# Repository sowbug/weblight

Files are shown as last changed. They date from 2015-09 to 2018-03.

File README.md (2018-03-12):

# WebLight

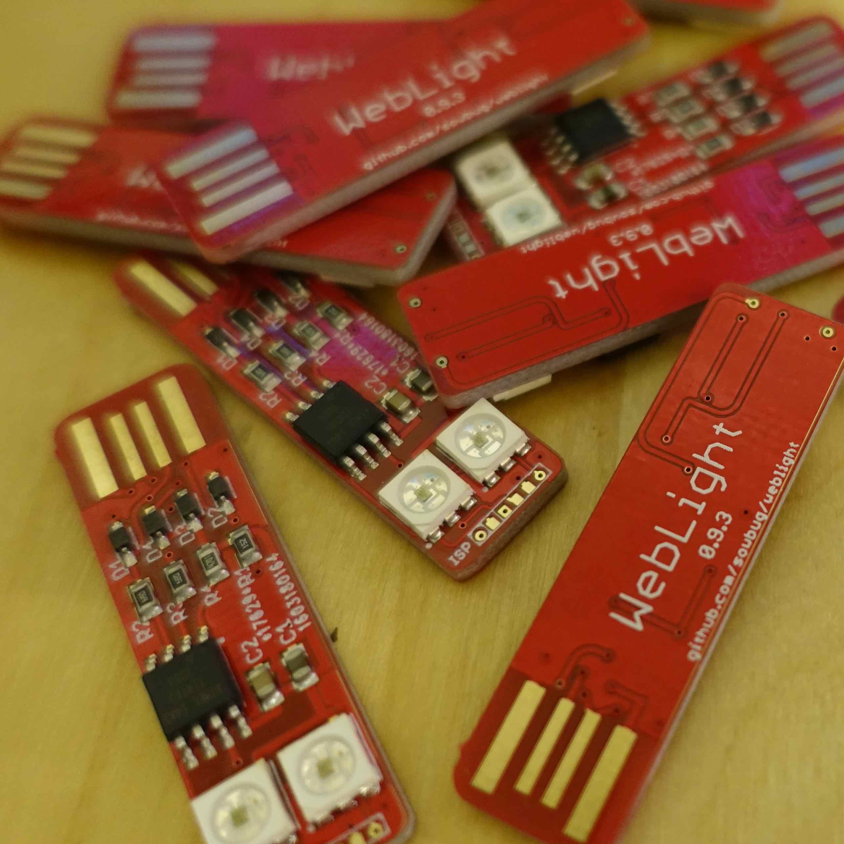
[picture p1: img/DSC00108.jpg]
WebLight


A USB-controlled LED designed for the
[WebUSB API](https://wicg.github.io/webusb/).

Try the web app
===
Have a WebLight device already?  
Launch the web app here:  
https://sowbug.github.io/weblight/

What does the javascript look like to write color values?  
Check out [software/src/weblight-card.html](https://github.com/sowbug/weblight/blob/master/software/src/weblight-card.html)

Developing WebLight Devices
===

Toolchain/environment setup
---

* Install avr-gcc. On Windows, download avr-gcc from
http://andybrown.me.uk/2015/03/08/avr-gcc-492/. Make sure you've
installed a base MinGW and MSYS system or equivalent, and have them in
your system path. On Linux, try something like `sudo apt-get install
gcc-avr binutils-avr gdb-avr avr-libc avrdude`. On OS X,
[CrossPack](https://www.obdev.at/products/crosspack/index.html) works.
* Install libusb. `sudo apt-get install libusb-dev` works on
  Linux, and `brew install libusb libusb-compat` works on OS X.
* Install pyusb. `sudo apt-get install python-usb` on Linux, or `sudo pip
  install pyusb` on other platforms.
* Build and install the
  [micronucleus command-line tool](https://github.com/micronucleus/micronucleus/tree/master/commandline)
  to be able to upload to the ATTiny85. Have it somewhere in your PATH. Don't forget [the udev rule](https://raw.githubusercontent.com/micronucleus/micronucleus/master/commandline/49-micronucleus.rules) if needed.
* Copy the files in `udev` to `/etc/udev/rules.d/` and then `sudo
  udevadm control --reload-rules`.

Programming a newly built board
---

* Connect a 6-pin AVR programmer. Note that if you've built the
  production version of the board, you'll need either an SOIC-8 clip
  manually wired for the ATtiny85, or else a
  [ProtoProg](http://protofusion.org/wordpress/2013/05/open-hardware-pogo-pin-programmer/)
  programming
  adapter. [This is the project I ordered](https://oshpark.com/shared_projects/fqvxyzoH)
  from OSH Park, and you'll want [0.68mm diameter, 16mm length pogo
  pins](http://www.ebay.com/sch/i.html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), probably from eBay.
* `cd firmware`
* Configure the makefile to talk to your type of programmer (default
usbtiny).
* `make factory` Now you have a bootloader-ready board with no firmware.
* Disconnect the programmer and plug it into a USB port.
* `make clean upload`

Mass-producing boards
---

This clones the complete firmware from an existing device. For
convenience, a relatively stable version of that complete firmware
image is already here in the repository (full-[version].hex). If you
overwrite it, we'll assume you know what you're doing.

1. Make one device using the instructions from the previous section.
1. Unplug from USB and attach to programmer.
1. `cd firmware`
1. `make create_full` This clones the firmware of the board you just
built.
1. Attach your next board to the programmer.
1. `make factory_mp`
1. Repeat last two steps for all remaining boards.

Development
---

1. In the `firmware` directory, `make clean upload`.
1. Plug in the board. After a few moments you should see `Micronucleus
   done. Thank you!`
1. Now the lights on the board should run a startup sequence.
1. Using `lsusb` you should see something like `Bus 001 Device 006: ID
   1209:a800 InterBiometrics`.

Usage
---

1. Install [PyUSB](http://walac.github.io/pyusb/). `sudo pip install
pyusb==1.0.0.b2`
1. From the base directory of the weblight project,
`./commandline/wlctl 800000` will give you a medium-brightness red
light (it uses CSS-style RGB color format).
1. `--help` for more options.

BOM for production (not developer) circuit
---

The best results are with an ENIG finish 2.0mm thickness PCB. If you're just prototyping, 1.6mm will work, but you'll want to put some thick solder on the USB leads to bulk them up a bit. Even then, the fit in the USB socket will be loose. ENIG takes longer to wear out than regular HASL.

The board measures 12mm x 41.1734mm x 2.0mm.

* C1: 1uF 0805 capacitor (DigiKey 311-1365-1-ND)
* C2: 0.1uF 0805 capacitor (DigiKey 311-1142-1-ND)
* D1, D2: 3.6V SOD-323 Zener diode. I successfully used BZT52C3V6S-7-F and MM3Z3V6T1G (DigiKey MM3Z3V6T1GOSCT-ND). According to [V-USB Hardware Considerations](http://vusb.wikidot.com/hardware), they should be "those that look like 1N4148 (usually 500 mW or less)"
* D3, D4: low forward-voltage SOD-323 diode (0.4-volt or less forward voltage so that the supply to the LEDs is higher than 4.5 volts). I have successfully used Toshiba 1SS367 (forward voltage about 0.3V, DigiKey 1SS367H3FCT-ND).
* LED1, LED2: APA102C LED (Real versions of these are not especially easy to find)
* R1: 1.5K 0805 resistor (DigiKey 311-1.5KARCT-ND)
* R2, R3: 68 0805 resistor (DigiKey 311-68ARCT-ND)
* R4: 10K 0805 resistor (DigiKey 311-10KARCT-ND)
* U1: ATtiny85 ATTINY85-20SU (DigiKey ATTINY85-20SURCT-ND)

Tips
---

* In addition to `wlctl` in the `commandline` directory, there is
`lswusb`, which attempts to parse WebUSB descriptors. This utility
will help you when you're developing your own WebUSB-compatible
device.

FAQ
===

* **What is WebUSB?** It's a [new web
  standard](https://reillyeon.github.io/webusb/) that makes it
  easy to write a USB driver once (in JavaScript) and have it work
  everywhere that WebUSB is supported.

* **Aren't there already a lot of USB-controlled lights out there?**
  Yes, it's more or less a rite of passage in hobbyist electronics to
  make some kind of blinking light. The purpose of this project was to
  design a very simple WebUSB device that might actually be useful.

* **You said "useful" in the prior answer. Please define that.** A
  WebUSB-enabled light can alert you of interesting things, like a
  broken continuous build, a service interruption, or yet another
  crash in the price of bitcoin.

* **Which board should I build?** If you're interested in hacking on
  the firmware, build
  [`weblight_developer.brd`](https://github.com/sowbug/weblight/blob/master/hardware/weblight_developer.brd). This
  one has a few more features that make firmware development more convenient. Otherwise if
  you just want a device to play with, build
  [`weblight.brd`](https://github.com/sowbug/weblight/blob/master/hardware/apa102/weblight.brd). That
  one is more compact, but it requires the ProtoProg ISP adapter, rather than the more common
  AVRISP 6-pin adapter. Both designs use 0805 SMT components. Either board can be ordered from [OSH Park](https://oshpark.com/) or [Seeed](https://www.seeedstudio.com/service/). Note that if you manufacture with a
  standard 1.6mm PCB, you'll have to solder the contacts to give them enough thickness to connect. For end-user
  boards, 2.0mm or 2.4mm will fit better in USB sockets, and ENIG finish will last longer without tarnishing.

* **I don't want to build a board, but I'd like one. Will you sell me one?** I don't have plans to mass-produce boards for sale. But if you're interested in getting one, [subscribe to notifications for this issue](https://github.com/sowbug/weblight/issues/31).

* **I remember reading something about Origin Trials. What does that have to do with WebUSB?** Chrome 61 and beyond ship with WebUSB, so if your users are running up-to-date Chrome, you're all set! But in case you're curious, the Chrome team has a system called Origin Trials for gathering real developer feedback on provisional APIs. Go to https://bit.ly/OriginTrials to learn more.

Acknowledgments
===

* Jenna Fox ([bluebie](https://github.com/bluebie)) and Tim ([cpldcpu](https://github.com/cpldcpu/)) for micronucleus advice. (Update December 2016: [Tim's article about SK9822](https://cpldcpu.com/2016/12/13/sk9822-a-clone-of-the-apa102/).)
* bobhackmelb on freenode for advice on PCB manufacturing, specifically thickness.
* [Passerby](http://electronics.stackexchange.com/users/17178/passerby) for help [reverse-engineering](http://electronics.stackexchange.com/questions/209941/two-sided-connectorless-usb-on-a-pcb) the double-sided USB connector.
* [gerblook.org](http://gerblook.org/) for an awesome Gerber visualizer.
* [Lars Knudsen](https://github.com/larsgk) for keeping docs up to date.

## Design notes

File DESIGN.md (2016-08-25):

WebLight Design
===

Goal
===

To create a simple and inexpensive device that shows off
[WebUSB](https://reillyeon.github.io/webusb/) and helps validate the
specification.

Overview
===

WebLight is a small circuit on a standalone printed circuit board that
contains multicolored lights controllable by the computer it's plugged
into. When plugged into a Type A USB receptable (the kind normally
found on desktop and laptop PCs), it appears as a custom-class USB
device that can be controlled by host software. Additionally, it
responds to requests for WebUSB descriptors that indicate its
willingness to communicate with certain web origins through the WebUSB
API.

The user benefit of WebUSB is that hardware devices are even more
plug-and-play than the traditional sense of that term: any
WebUSB-compatible device will work without the requirement to install
USB drivers.

Circuit
===

* Influenced by
[Adafruit Trinket](https://learn.adafruit.com/introducing-trinket/downloads),
[V-USB design suggestions](http://vusb.wikidot.com/hardware), and the
[DigiSpark](https://digistump.com/wiki/digispark/tutorials/digispark).

* We chose the "Level conversion on D+ and D-" option for solving the
mismatch between 5v AVR/LED and 3.3v USB data lines. The reason we
picked that approach rather than a lower-voltage AVR circuit is that
it requires fewer and less-expensive components, and the disadvantages
("Not a clean solution," slight power wastage) wouldn't affect the end
product in noticeable ways.

PCB
===

* HASL (Hot Air Solder Leveling) is cheapest and easiest for manual
soldering, but it usually contains lead (lead-free HASL is available).

* ENIG (Electroless Nickel Immersion Gold) is expensive and looks
nice. It's harder to deal with when manually soldering.

* Most connectorless PCBs in production range from 2.4 to 2.6mm in
thickness. This thickness is not available from short-run PCB
manufacturers.

* 2.0mm is
[reputed](http://electronics.stackexchange.com/questions/13174/connectorless-usb-on-a-pcb)
to work OK, and short-run PCB manufacturers support it.

* The SparkFun EAGLE part for connectorless type-A says "If possible,
ensure that your PCB is about 2.4mm thick to fit snugly."

* 1.6mm is typical for prototyping PCBs. This works with a piece of
paper taped on the back of the PCB, beneath the connector area.
Otherwise it's a loose fit that is unreliable in some USB ports.

* Typical width of connectorless PCBs is 12mm.

* Length doesn't matter, except for ergonomics.

* Making the PCB pluggable in either direction (upside-down or normal)
requires extra diodes.

Microcontroller
===

* Atmel AVR is inexpensive and has a fully open toolchain. I have
experience with AVR.

* Microchip PIC is usually the other contender. I don't have
experience with PICs. While there are free compilers, the widely used
ones are not open. For at least the past five years, the open-source
[SDCC](http://sdcc.sourceforge.net/) has been aiming to support PIC16
and PIC18.

* The [ATTiny85](http://www.atmel.com/devices/attiny85.aspx) is a
popular choice for small applications that bitbang USB. The SOIC8
version costs about 75 cents in quantity 100+.

* The ATMega 'u2 and 'u4 series have built-in USB support, but they are
relatively expensive (more than $3/unit in quantity).

LED
===

* The WS2812B is the current hobbyist's choice for low-cost
addressable RGB LED. It has substantial software support thanks in
part to the [Adafruit Neopixel](http://www.adafruit.com/category/168)
brand. Brightness is adequate; maximum current is about 60mA at 5V.
Disadvantages: the component has a reputation for being easily killed
by voltage spikes, leading to
[best-practice recommendations](https://learn.adafruit.com/adafruit-neopixel-uberguide/best-practices)
to protect with large capacitors and resistors. The chip protocol is
extremely timing-sensitive, meaning it will monopolize the
microcontroller's execution for significant periods of time. Finally,
the refresh rate is relatively low (400Hz), which makes it
inappropriate for some applications (but isn't a consideration for
this design).

* The APA102C has a similar form factor to the WS2812B (5050 SMD) and
similar luminosity and power characteristics. However, it uses an
SPI-like protocol that is not sensitive to timing, making it ideal for
an application like this where the microcontroller will be servicing
timing-sensitive bitbanged USB requests. As of October 2015, is
slightly more expensive than the WS2812 in quantity (12 cents vs. 10
cents), but because the maker and DIY lighting communities are
embracing it, its price should come down soon.

Firmware
===

* [V-USB](https://www.obdev.at/products/vusb/) is the standard for AVR
USB bitbanging. Its
[license terms](https://www.obdev.at/products/vusb/license.html) are
annoying but tolerable for this entirely open-source project.

* [Micronucleus](https://github.com/micronucleus/micronucleus/) is a
bootloader based on V-USB. It has a smaller binary size, is reported
to be faster, and claims better compatibility.

* Having a bootloader is desirable during development, and likely to
be useful to update production devices. It might turn out to be
unnecessary for production devices, but today there is little cost to
keeping it because we aren't bumping up against program-space limits.

* [light_ws2812](https://github.com/cpldcpu/light_ws2812) is a much
lighterweight WS2812 library compared to
[Adafruit NeoPixel](https://github.com/adafruit/Adafruit_NeoPixel). (As
noted above, WS2812 is not the long-term choice for this project.)
This library also includes support for the APA102 chipset.

* As shown in the
[Adafruit DotStar](https://github.com/adafruit/Adafruit_DotStar)
Arduino and [Polulu](https://github.com/pololu/apa102-arduino)
libraries for APA102, there isn't a tremendous need for a large
or resource-intensive software library for this LED.

* TODO: describe V-USB and usbFunctionSetup()

WebUSB
===

* TODO

* TODO: describe challenge with WinUSB

USB VID/PID
===

* [pid.codes](http://pid.codes/) provides one-off maker/hobbyist
VID/PID pairs, eliminating the need to use garbage pairs or submit to
the
[burdensome and expensive requirements](http://www.usb.org/developers/vendor/)
of the USB Implementers Forum.

Prototype Manufacturing
===

* [OSH Park](https://oshpark.com/)

* [MacroFab](http://macrofab.net/)

Production Manufacturing
===

* TODO

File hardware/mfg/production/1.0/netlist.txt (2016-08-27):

Netlist

Exported from weblight.sch at 8/27/16 8:51 AM

EAGLE Version 7.6.0 Copyright (c) 1988-2016 CadSoft

Net             Part     Pad      Pin        Sheet

5V-BOT          D4       A        A          1
                J-BOT    5V       VBUS       1

5V-TOP          D3       A        A          1
                J-TOP    5V       VBUS       1

CLK_1/SCK       ISP      4        SCK        1
                LED1     CI       CI         1
                U1       7        PB2(SCK/ADC1) 1

CLK_2           LED1     CO       CO         1
                LED2     CI       CI         1

DIN_1/MOSI      ISP      2        MOSI       1
                LED1     DI       DI         1
                U1       5        PB0(MOSI)  1

DIN_2           LED1     DO       DO         1
                LED2     DI       DI         1

GND             C1       1        1          1
                C2       1        1          1
                D1       A        A          1
                D2       A        A          1
                ISP      5        GND        1
                J-BOT    GND      GND        1
                J-TOP    GND      GND        1
                LED1     GND      GND        1
                LED2     GND      GND        1
                U1       4        GND        1

MISO            ISP      3        MISO       1
                U1       6        PB1(MISO)  1

N_RESET         ISP      1        \RST       1
                R4       2        2          1
                U1       1        PB5(NRES)  1

USB_D_MINUS     R3       2        2          1
                U1       2        PB3(ADC3)  1

USB_D_MINUS_RAW D2       C        C          1
                J-BOT    USB_M    D-         1
                J-TOP    USB_M    D-         1
                R1       1        1          1
                R3       1        1          1

USB_D_PLUS      R2       1        1          1
                U1       3        PB4(ADC2)  1

USB_D_PLUS_RAW  D1       C        C          1
                J-BOT    USB_P    D+         1
                J-TOP    USB_P    D+         1
                R2       2        2          1

VCC             C1       2        2          1
                C2       2        2          1
                D3       C        C          1
                D4       C        C          1
                ISP      6        VCC        1
                LED1     VCC      VCC        1
                LED2     VCC      VCC        1
                R1       2        2          1
                R4       1        1          1
                U1       8        VCC        1

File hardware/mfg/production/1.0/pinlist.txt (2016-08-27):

Pinlist

Exported from weblight.sch at 8/27/16 8:51 AM

EAGLE Version 7.6.0 Copyright (c) 1988-2016 CadSoft

Part     Pad      Pin        Dir      Net

C1       1        1          pas      GND
         2        2          pas      VCC

C2       1        1          pas      GND
         2        2          pas      VCC

D1       A        A          pas      GND
         C        C          pas      USB_D_PLUS_RAW

D2       A        A          pas      GND
         C        C          pas      USB_D_MINUS_RAW

D3       A        A          pas      5V-TOP
         C        C          pas      VCC

D4       A        A          pas      5V-BOT
         C        C          pas      VCC

ISP      1        \RST       io       N_RESET
         2        MOSI       io       DIN_1/MOSI
         3        MISO       io       MISO
         4        SCK        io       CLK_1/SCK
         5        GND        io       GND
         6        VCC        io       VCC

J-BOT    5V       VBUS       io       5V-BOT
         GND      GND        io       GND
         USB_M    D-         io       USB_D_MINUS_RAW
         USB_P    D+         io       USB_D_PLUS_RAW

J-TOP    5V       VBUS       io       5V-TOP
         GND      GND        io       GND
         USB_M    D-         io       USB_D_MINUS_RAW
         USB_P    D+         io       USB_D_PLUS_RAW

LED1     CI       CI         in       CLK_1/SCK
         CO       CO         out      CLK_2
         DI       DI         in       DIN_1/MOSI
         DO       DO         out      DIN_2
         GND      GND        pwr      GND
         VCC      VCC        pwr      VCC

LED2     CI       CI         in       CLK_2
         CO       CO         out               *** unconnected ***
         DI       DI         in       DIN_2
         DO       DO         out               *** unconnected ***
         GND      GND        pwr      GND
         VCC      VCC        pwr      VCC

R1       1        1          pas      USB_D_MINUS_RAW
         2        2          pas      VCC

R2       1        1          pas      USB_D_PLUS
         2        2          pas      USB_D_PLUS_RAW

R3       1        1          pas      USB_D_MINUS_RAW
         2        2          pas      USB_D_MINUS

R4       1        1          pas      VCC
         2        2          pas      N_RESET

U1       1        PB5(NRES)  io       N_RESET
         2        PB3(ADC3)  io       USB_D_MINUS
         3        PB4(ADC2)  io       USB_D_PLUS
         4        GND        io       GND
         5        PB0(MOSI)  io       DIN_1/MOSI
         6        PB1(MISO)  io       MISO
         7        PB2(SCK/ADC1) io       CLK_1/SCK
         8        VCC        io       VCC

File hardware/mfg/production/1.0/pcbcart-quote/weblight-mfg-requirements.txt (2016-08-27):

Special requirements for WebLight-1.0

- PCB color black
- PCB thickness 2.0mm
- PCB finish ENIG
- 13 SMD parts
- 9 BOM lines
- 0 TH parts
- ISP, J-TOP, J-BOT, FID1 are empty parts - no placements

Project page is at https://github.com/sowbug/weblight

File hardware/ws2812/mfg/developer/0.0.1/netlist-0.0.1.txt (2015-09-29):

Netlist

Exported from usb-led.sch at 9/28/2015 10:41 PM

EAGLE Version 7.4.0 Copyright (c) 1988-2015 CadSoft

Net             Part       Pad      Pin        Sheet

DIN_2           D3         2        DOUT       1
                D4         4        DIN        1

GND             C1         2        2          1
                C2         2        2          1
                D1         A        A          1
                D2         A        A          1
                D3         3        VSS        1
                D4         3        VSS        1
                JP-ISP     6        6          1
                JP-USB-BOT GND      GND        1
                JP-USB-TOP GND      GND        1
                U1         4        GND        1

MISO            JP-ISP     1        1          1
                U1         6        PB1(MISO)  1

MOSI/DIN        D3         4        DIN        1
                JP-ISP     4        4          1
                U1         5        PB0(MOSI)  1

RESET           JP-ISP     5        5          1
                U1         1        PB5(NRES)  1

SCK             JP-ISP     3        3          1
                U1         7        PB2(SCK/ADC1) 1

USB_D_MINUS     R3         2        2          1
                U1         2        PB3(ADC3)  1

USB_D_MINUS_RAW D2         C        C          1
                JP-USB-BOT USB_M    D-         1
                JP-USB-TOP USB_M    D-         1
                R1         1        1          1
                R3         1        1          1

USB_D_PLUS      R2         2        2          1
                U1         3        PB4(ADC2)  1

USB_D_PLUS_RAW  D1         C        C          1
                JP-USB-BOT USB_P    D+         1
                JP-USB-TOP USB_P    D+         1
                R2         1        1          1

VCC             C1         1        1          1
                C2         1        1          1
                D3         1        VDD        1
                D4         1        VDD        1
                JP-ISP     2        2          1
                JP-USB-BOT 5V       VBUS       1
                JP-USB-TOP 5V       VBUS       1
                R1         2        2          1
                U1         8        VCC        1

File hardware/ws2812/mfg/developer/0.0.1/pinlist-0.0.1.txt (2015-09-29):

Pinlist

Exported from usb-led.sch at 9/28/2015 10:42 PM

EAGLE Version 7.4.0 Copyright (c) 1988-2015 CadSoft

Part       Pad      Pin        Dir      Net

C1         1        1          pas      VCC
           2        2          pas      GND

C2         1        1          pas      VCC
           2        2          pas      GND

D1         A        A          pas      GND
           C        C          pas      USB_D_PLUS_RAW

D2         A        A          pas      GND
           C        C          pas      USB_D_MINUS_RAW

D3         1        VDD        pwr      VCC
           2        DOUT       out      DIN_2
           3        VSS        pwr      GND
           4        DIN        in       MOSI/DIN

D4         1        VDD        pwr      VCC
           2        DOUT       out               *** unconnected ***
           3        VSS        pwr      GND
           4        DIN        in       DIN_2

JP-ISP     1        1          pas      MISO
           2        2          pas      VCC
           3        3          pas      SCK
           4        4          pas      MOSI/DIN
           5        5          pas      RESET
           6        6          pas      GND

JP-USB-BOT 5V       VBUS       io       VCC
           GND      GND        io       GND
           USB_M    D-         io       USB_D_MINUS_RAW
           USB_P    D+         io       USB_D_PLUS_RAW

JP-USB-TOP 5V       VBUS       io       VCC
           GND      GND        io       GND
           USB_M    D-         io       USB_D_MINUS_RAW
           USB_P    D+         io       USB_D_PLUS_RAW

R1         1        1          pas      USB_D_MINUS_RAW
           2        2          pas      VCC

R2         1        1          pas      USB_D_PLUS_RAW
           2        2          pas      USB_D_PLUS

R3         1        1          pas      USB_D_MINUS_RAW
           2        2          pas      USB_D_MINUS

U1         1        PB5(NRES)  io       RESET
           2        PB3(ADC3)  io       USB_D_MINUS
           3        PB4(ADC2)  io       USB_D_PLUS
           4        GND        io       GND
           5        PB0(MOSI)  io       MOSI/DIN
           6        PB1(MISO)  io       MISO
           7        PB2(SCK/ADC1) io       SCK
           8        VCC        io       VCC

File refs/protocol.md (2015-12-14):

The device's VID/PID pair is 1209/a800. All communications with the
device, aside from basic USB communication like the device-descriptor
request, are by control transfers.

0: WL_REQUEST_ECHO
---

Writes back to the host the four bytes in wValue and wIndex. Used to
test that the host and device can communicate reliably.

1: WL_REQUEST_SET_RGB
---

Sets the RGB color of all LEDs. Three bytes sent as OUT data.

80 00 00 will set the LEDs to medium-brightness red.

00 00 80 will set the LEDs to medium-brightness blue.

2: WL_REQUEST_SET_LED_COUNT
---

Sets the number of active LEDs. Pass the number in wValue. The value
is written to EEPROM. This request exists to allow the same firmware
image to work on different versions of the hardware. It should be
correctly set at the factory. There should be no need for application
developers to use this request. TODO: deprecate or at least move out
of the low request enum area where developers won't use it by
accident.

252: WL_REQUEST_WINUSB
---

Requests WinUSB descriptors.

253: WL_REQUEST_RESET_DEVICE
---

Resets the device and puts it into bootloader mode.

254: WL_REQUEST_WEBUSB
---

Requests WebUSB descriptors.

Ideas
---

* Set duty cycle: % of time lights should be on, and duration of cycle

* SET_HSV: hue/saturation/value as alternative to RGB

* Set sequence: each byte is an index into palette? Speed?

* Persistent: sequence to appear on startup, on heartbeat failure, or
  just on demand.

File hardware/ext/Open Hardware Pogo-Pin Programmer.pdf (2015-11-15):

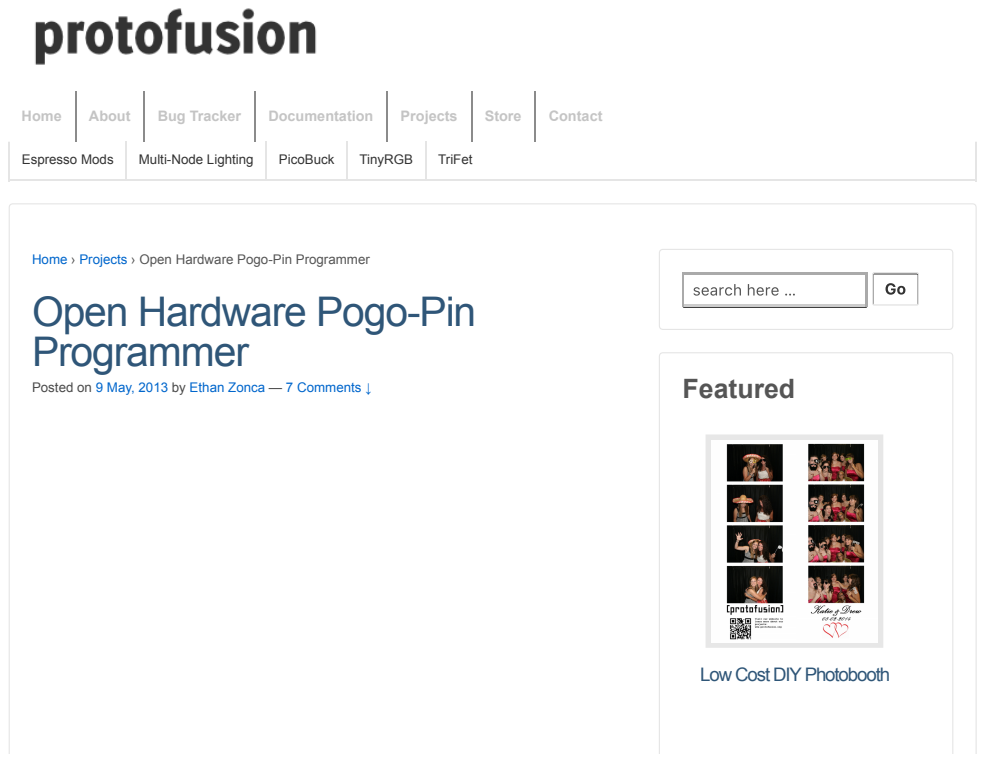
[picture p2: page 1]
search here …; Featured

Home (http://protofusion.org/wordpress/) | About (http://protofusion.org/wordpress/about/) | Bug Tracker (http://protofusion.org/flyspray/) | Documentation (http://protofusion.org/wiki/) | Projects (http://protofusion.org/wordpress/projects-list/) | Store (https://www.tindie.com/stores/protofusion/) | Contact

Espresso Mods (http://protofusion.org/wordpress/category/projects/espresso-mods/) | Multi-Node Lighting (http://protofusion.org/wordpress/category/projects/avr/mnl/) | PicoBuck (http://protofusion.org/wordpress/category/projects/picobuck/) | TinyRGB (http://protofusion.org/wordpress/category/projects/tinyrgb/) | TriFet (http://protofusion.org/wordpress/category/projects/trifet/)

Home (http://protofusion.org/wordpress/) › Projects (http://protofusion.org/wordpress/category/projects/) › Open Hardware Pogo-Pin Programmer
Open Hardware Pogo-Pin
Programmer (http://protofusion.org/wordpress/2013/05/open-hardware-pogo-pin-programmer/)

Posted on 9 May, 2013 (http://protofusion.org/wordpress/2013/05/open-hardware-pogo-pin-programmer/) by Ethan Zonca (http://protofusion.org/wordpress/author/admin/) — 7 Comments ↓

Low Cost DIYPhotobooth (http://protofusion.org/wordpress/2015/02/low-cost-diy-photobooth/)

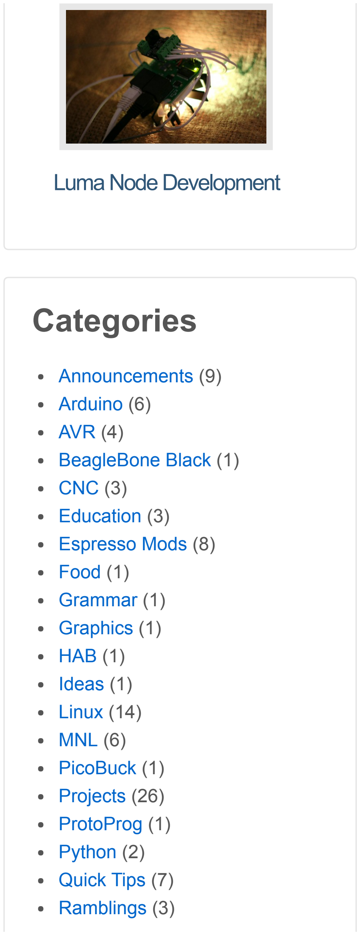
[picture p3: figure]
Luma Node Development; Categories; Announcements (9) Arduino (6) AVR (4) BeagleBone Black (1) CNC (3) Education (3) Espresso Mods (8) Food (1) Grammar (1) Graphics (1) HAB (1) Ideas (1) Linux (14) MNL (6) PicoBuck (1) Projects (26) ProtoProg (1) Python (2) Quick Tips (7) Ramblings (3)
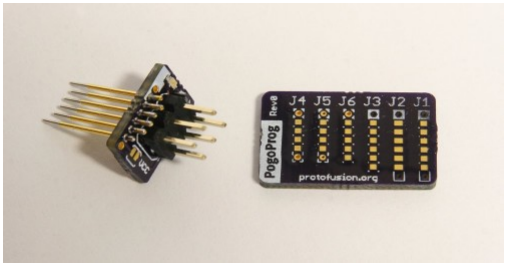
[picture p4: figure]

The ProtoProg is a small open source hardware pogo pin programming solution. The ProtoProg does not need a physical connector on the board, it uses surfacemount pads for signals and thruholes for alignment. Two standard footprints are available, the smallest of which takes up very little space–only 7.6mm x 1.2mm!

# Design

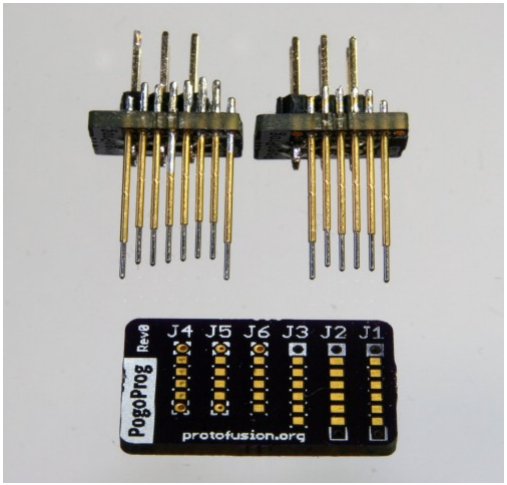
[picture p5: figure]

The ProtoProg was originally designed for use with AVR microcontroller programming (using 6 pins), but this design can easily be repurposed for other programmers. Several footprints are available for this programming connector as shown on the test PCB above, but only two are recommended for realworld use:

J1 (ProtoProg Standard) – Small pads with alignment holes (8 pins required) J4 (ProtoProg Micro) – Small pads with alignment vias (6 pins required) ridik (http://protofusion.org/wordpress/category/ridik/) (4)
Technology (http://protofusion.org/wordpress/category/technology/) (7)
therm (http://protofusion.org/wordpress/category/projects/therm/) (1)
TinyRGB (http://protofusion.org/wordpress/category/projects/tinyrgb/) (1)
TriFet (http://protofusion.org/wordpress/category/projects/trifet/) (1)
Uncategorized (http://protofusion.org/wordpress/category/uncategorized/) (4)
Web (http://protofusion.org/wordpress/category/web/) (4)

Choose the micro footprint for small size

J4 does not include any dedicated alignment holes and instead uses two of the signal lines with vias for pin alignment. The pogo pins do not go through the vias, they rest on top of the vias and “snap” into place for alignment. This footprint is very compact.

Choose the standard footprint for easier alignment

The standard footprint includes dedicated alignment holes, and requires 8 pins to be populated on the ProtoProg programming adapter. This connector takes up more lateral room, but allows for easier insertion and likely more reliable longterm use.

# Assembling the ProtoProg

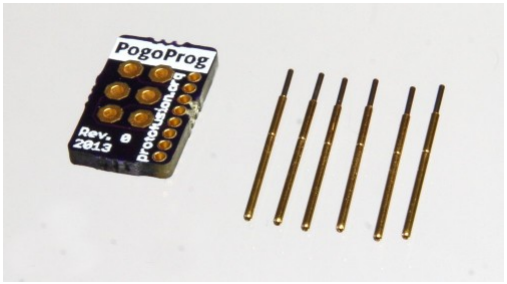
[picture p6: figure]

To begin, make sure you have these components:

6 or 8 pogo pins (depending on which footprint you want to use) [ebay] (http://www.ebay.com/sch/i.html?_sacat=0&_from=R40) 2 ProtoProg PCBs (one is used for alignment) [gerbers provided below] Vise (recommended)
Soldering iron and solder

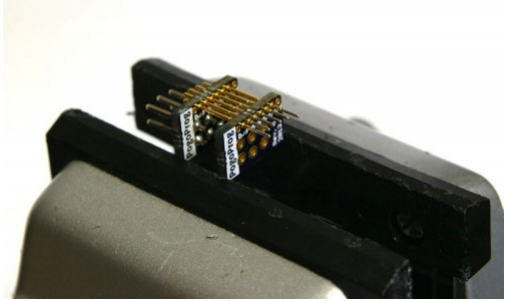
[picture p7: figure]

First, take one of the ProtoProg adapter PCBs and solder a 6×2 pin header on the top side.

If you are using an AVR programmer, I recommend soldering the VCC solderjumper on the top of the PCB. This allows your programmer to detect target voltage and power the target (if your programmer supports this feature). You can also solder on an optional LED and current limiting resistor, which is placed on the AVR ISP VCC pin.

Next, take your ProtoProg board with the 6×2 pin header and a blank ProtoProg board and place them in your vise (see photo above). Carefully insert pogo pins into each hole before you completely tighten the vise. This will align the pins before you solder them.

Next, align the pins so that the two outside pins stick out about 3mm past the other pins. These pins will make contact with the alignment holes on the footprint before the rest of the signal pins.

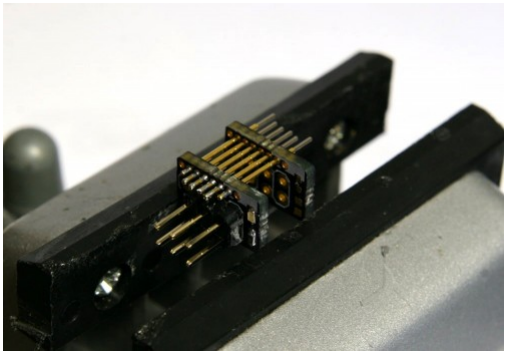
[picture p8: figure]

Finally, solder each pin to the PCB. Make sure each pin makes a good solder joint with the pads, as these joints form both an electrical and mechanical connection.

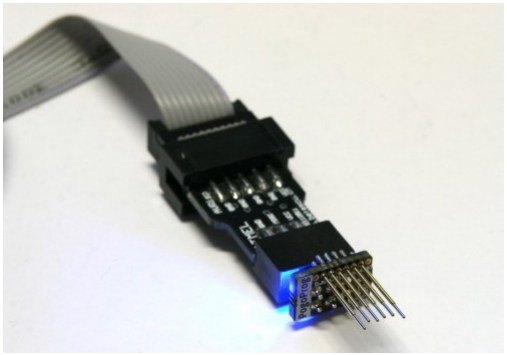
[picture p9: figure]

Finally, attach your programming adapter to your programmer. If your programmer is configured to power your target board, the ProtoProg LED will illuminate. If the target is selfpowered, the LED will illuminate when you plug the ProtoProg into your target board.

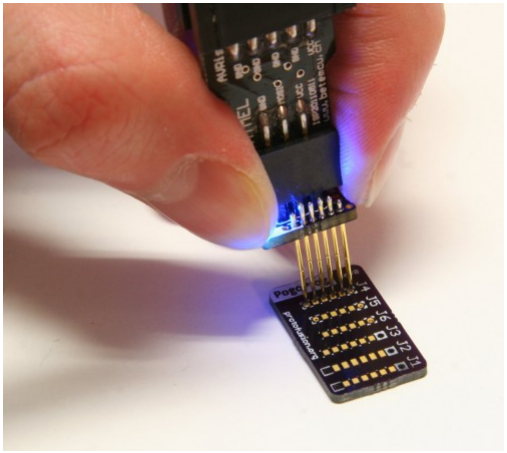
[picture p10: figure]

When programming, carefully press the ProtoProg adapter on your footprint. If you are using the micro connector, make sure the two outer pins “snap” into the alignment vias before fully pressing down the connector.

If you are using the standard connector, make sure the two outer alignment pins go into the outer alignment holes before completely pressing down the connector.

Note: This project was recently renamed, but the PCBs and photos above still bear the

‹ PicoBuck RGB LED Driver (http://protofusion.org/wordpress/2013/03/picobuck-rgb-led-driver/) | BeagleBone Black and DTC (http://protofusion.org/wordpress/2013/06/beaglebone-black-and-dtc/) ›

old name.

# Design Resources

Protofusion Eagle Library (http://protofusion.org/hg/protofusion-hardware/raw-file/default/lbr/Protofusion.lbr) (footprints for your own PCBs) ProtoProgAdapter v1.0 (http://protofusion.org/wordpress/wp-content/uploads/2013/04/PogoProg-RTM1.zip) (readytofab gerbers for OSH Park) (http://oshpark.com/)
ProtoProg Adapter v1.0 (http://protofusion.org/wordpress/wp-content/uploads/2013/04/pogoProg.zip) (Eagle design files)

If you have any questions or suggestions, leave a comment below or send a message through our contact page. (http://protofusion.org/wordpress/contact/)

Related posts:

1. Open Hardware USB to RS485 Adapter (http://protofusion.org/wordpress/2013/07/open-hardware-usb-to-rs485-adapter/)
2. RJ-45 Breakout (http://protofusion.org/wordpress/2013/08/rj-45-breakout/)
3. ZonCoffee Hardware (http://protofusion.org/wordpress/2011/01/zoncoffee-hardware/)

About Ethan Zonca (http://protofusion.org/wordpress/author/admin/)
Ethan is a computer engineer and open source hardware/software developer from Michigan. He enjoys AVR and linux development, photography, mountain biking, and drinking significant amounts of homeroasted coffee. Find out more at ethanzonca.com.

Tagged with: AVR, (http://protofusion.org/wordpress/tag/avr/) ICSP, (http://protofusion.org/wordpress/tag/icsp/) Open-Source Hardware, (http://protofusion.org/wordpress/tag/open-source-hardware/) OSHW, (http://protofusion.org/wordpress/tag/oshw/) Pogo Pin, (http://protofusion.org/wordpress/tag/pogo-pin/) Programmer (http://protofusion.org/wordpress/tag/programmer/) Posted in Projects, (http://protofusion.org/wordpress/category/projects/) ProtoProg (http://protofusion.org/wordpress/category/projects/protoprog/)

### 7 comments on “Open Hardware Pogo-Pin Programmer”

mossmann (http://ossmann.blogspot.com/) says:

10 December, 2013 at 7:15 pm (http://protofusion.org/wordpress/2013/05/open-hardware-pogo-pin-programmer/comment-page-1/)

Would you mind googling before you name your next project?

http://ubertooth.sourceforge.net/hardware/program/

Pogoprog is a spring pin FTDI board developed as part of the Ubertooth project. It can be used to program LPC17xx and many other microcontrollers with ISP.

Reply (http://protofusion.org/wordpress/2013/05/open-hardware-pogo-pin-programmer/?replytocom=163719)

Ethan Zonca (http://protofusion.org/) says:

10 December, 2013 at 7:35 pm (http://protofusion.org/wordpress/2013/05/open-hardware-pogo-pin-programmer/comment-page-1/)

Sorry about that! This was an internal project we were testing on one of our boards, and I just stuck with the random name we came up with. I added a note to clarify at the beginning of the post with a link to your site.

Edit: Just did a little find/replace on this page. The images don’t match the text, but that shouldn’t cause too much trouble

Scott Harden (http://www.swharden.com/) says:

11 December, 2013 at 8:23 pm (http://protofusion.org/wordpress/2013/05/open-hardware-pogo-pin-programmer/comment-page-1/)

wow, that’s really disappointing. I second this – I’ve seen “Pogoprog” before and I was surprised that this website isn’t actually it. It was the ubertooth page I was thinking of.

PLEASE use a unique, new name. If you “accidentally” use the identical name as someone else, at LEAST make sure you’re not naming and selling a nearly identical product.

Stay tuned! Next week we will demonstrate our new Interchangeable Bootloading Module, which will will call “IBM”

mossmann (http://ossmann.blogspot.com/) says:

18 December, 2013 at 1:28 am (http://protofusion.org/wordpress/2013/05/open-hardware-pogo-pin-programmer/comment-page-1/)

It was super nice of you to change the name so quickly. A++ WOULD BERATE AGAIN

Jack says:

12 December, 2013 at 11:35 am (http://protofusion.org/wordpress/2013/05/open-hardware-pogo-pin-programmer/comment-page-1/)

Excellent work, even J1 makes the standard programming pins look prehistoric. A next step might be to add some method to keep the programmer in place. Magnets perhaps.

PS, the comments about naming seem a little harsh. Granted someone else is already using the pogoplug name, but given a programmer based around pogopins, it’s not as the though that name is worthy of an award for originality.

Reply (http://protofusion.org/wordpress/2013/05/open-hardware-pogo-pin-programmer/?replytocom=165183)

allankliu (http://allankliu.blogspot.com/) says:

5 April, 2014 at 6:52 pm (http://protofusion.org/wordpress/2013/05/open-hardware-pogo-pin-programmer/comment-page-1/)

P50 J1 for pogopin?

I want to build one for JTAG/SWD used in most of Cortex-M micros.

I am still struggling there is not a standard pinout for reduced connectors.

Min: VSS/DIO/CLK/
Max: VSS/VDD/DIO/CLK/RST

Segger defined a standard pinout as “niddle kit”, which use 5×2 pinout.

Reply (http://protofusion.org/wordpress/2013/05/open-hardware-pogo-pin-programmer/?replytocom=248897)

Ethan Zonca (http://protofusion.org/) says:

14 April, 2014 at 7:42 pm (http://protofusion.org/wordpress/2013/05/open-hardware-pogo-pin-programmer/comment-page-1/)

For SWD you can get away with VSS/DIO/CLK, but some programmers want to sense the target voltage so you might want to use Vdd as well. I haven’t had a need for reset and the boundary scan SWO pin, but they are needed for some use cases.

### 3 Pings/Trackbacks for "Open Hardware Pogo-Pin Programmer"

Open Hardware Pogo-Pin Programmer | Juanjo Pina (http://juanjopina.wordpress.com/2013/05/09/open-hardware-pogo-pin-programmer/) says:

9 May, 2013 at 6:57 am (http://protofusion.org/wordpress/2013/05/open-hardware-pogo-pin-programmer/comment-page-1/)

[…] See on protofusion.org […]

» Enlaces Interesantes XII La Pizarra de Litox (http://litox.entramado.net/2013/06/02/enlaces-interesantes-xii/) says:

2 June, 2013 at 5:10 pm (http://protofusion.org/wordpress/2013/05/open-hardware-pogo-pin-programmer/comment-page-1/)

[…] Open Hardware Pogo-Pin Programmer: Un conector para programar que no necesita hembra, sólo unos agujeros de una forma concreta. […]

Therm: a Tiny PID Controller | [protofusion] (http://protofusion.org/wordpress/2015/08/therm-a-tiny-pid-controller-2/) says:

23 August, 2015 at 9:09 pm (http://protofusion.org/wordpress/2013/05/open-hardware-pogo-pin-programmer/comment-page-1/)

[…] bottom of the board expose the SWD interface for debugging and programming in a fixture or with a PogoProg […]

# Leave a Reply

Your email address will not be published. Required fields are marked *

Name *

E-mail *

Website

Comment

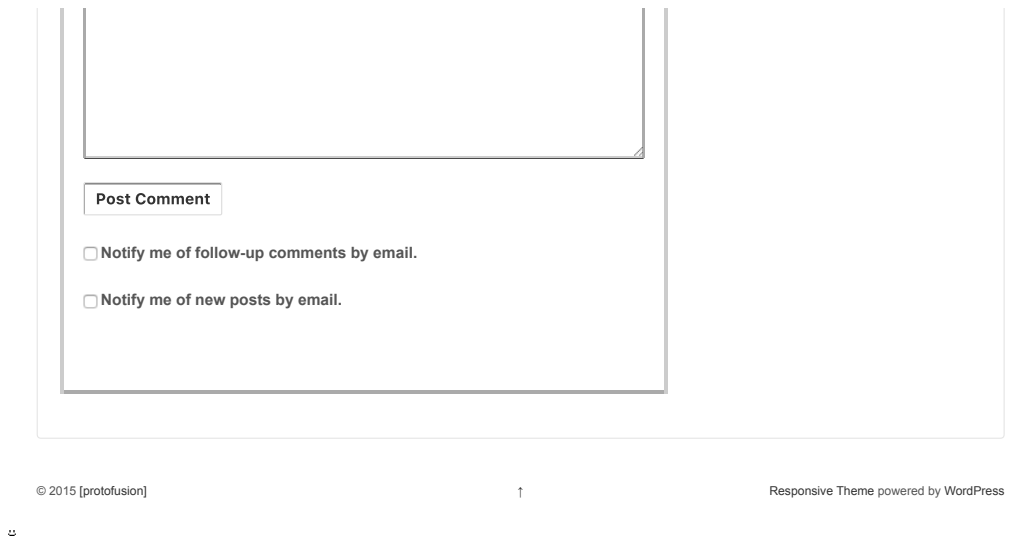
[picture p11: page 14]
© 2015 [protofusion]; Responsive Theme powered by WordPress; Post Comment

Notify me of followup comments by email.

Notify me of new posts by email.

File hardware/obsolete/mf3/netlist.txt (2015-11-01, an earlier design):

Netlist

Exported from weblight.sch at 10/31/15 9:27 PM

EAGLE Version 7.4.0 Copyright (c) 1988-2015 CadSoft

Net             Part         Pad      Pin        Sheet

CLK_1           LED1         CI       CI         1
                U1           7        PB2(SCK/ADC1) 1

CLK_2           LED1         CO       CO         1
                LED2         CI       CI         1

CLK_3           LED2         CO       CO         1
                LED3         CI       CI         1

CLK_4           LED3         CO       CO         1
                LED4         CI       CI         1

DIN_1           LED1         DI       DI         1
                R5           1        1          1

DIN_2           LED1         DO       DO         1
                LED2         DI       DI         1

DIN_3           LED2         DO       DO         1
                LED3         DI       DI         1

DIN_4           LED3         DO       DO         1
                LED4         DI       DI         1

DIN_RAW         R5           2        2          1
                U1           5        PB0(MOSI)  1

GND             C1           2        2          1
                C2           2        2          1
                D1           A        A          1
                D2           A        A          1
                JP-USB-MICRO 5        GND        1
                JP-USB-TOP   GND      GND        1
                LED1         GND      GND        1
                LED2         GND      GND        1
                LED3         GND      GND        1
                LED4         GND      GND        1
                U1           4        GND        1

N_RESET         R4           2        2          1
                U1           1        PB5(NRES)  1

SLD             JP-USB-MICRO S1       SLD        1
                JP-USB-MICRO S2       SLD        1
                JP-USB-MICRO S3       SLD        1
                JP-USB-MICRO S4       SLD        1
                JP-USB-MICRO S5       SLD        1
                JP-USB-MICRO S6       SLD        1

USB_D_MINUS     R3           2        2          1
                U1           2        PB3(ADC3)  1

USB_D_MINUS_RAW D2           K        C          1
                JP-USB-MICRO 2        D-         1
                JP-USB-TOP   USB_M    D-         1
                R1           1        1          1
                R3           1        1          1

USB_D_PLUS      R2           2        2          1
                U1           3        PB4(ADC2)  1

USB_D_PLUS_RAW  D1           K        C          1
                JP-USB-MICRO 3        D+         1
                JP-USB-TOP   USB_P    D+         1
                R2           1        1          1

VCC             C1           1        1          1
                C2           1        1          1
                JP-USB-MICRO 1        5V         1
                JP-USB-TOP   5V       VBUS       1
                LED1         VCC      VCC        1
                LED2         VCC      VCC        1
                LED3         VCC      VCC        1
                LED4         VCC      VCC        1
                R1           2        2          1
                R4           1        1          1
                U1           8        VCC        1

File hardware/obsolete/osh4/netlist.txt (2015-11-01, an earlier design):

Netlist

Exported from weblight_developer.sch at 10/31/15 8:44 PM

EAGLE Version 7.4.0 Copyright (c) 1988-2015 CadSoft

Net             Part       Pad      Pin        Sheet

DIN_1           LED1       DI       DI         1
                R4         2        2          1

DIN_2           LED1       DO       DO         1
                LED2       DI       DI         1

GND             C1         2        2          1
                C2         2        2          1
                D1         A        A          1
                D2         A        A          1
                JP-USB-TOP GND      GND        1
                JP1        6        6          1
                LED1       GND      GND        1
                LED2       GND      GND        1
                SW_RESET   PAD2     P$2        1
                U1         4        GND        1

MISO            JP1        1        1          1
                U1         6        PB1(MISO)  1

MOSI/DIN_RAW    JP1        4        4          1
                R4         1        1          1
                U1         5        PB0(MOSI)  1

RESET           JP1        5        5          1
                SW_RESET   PAD1     P$1        1
                U1         1        PB5(NRES)  1

SCK_1           JP1        3        3          1
                LED1       CI       CI         1
                U1         7        PB2(SCK/ADC1) 1

SCK_2           LED1       CO       CO         1
                LED2       CI       CI         1

USB_D_MINUS     R3         1        1          1
                U1         2        PB3(ADC3)  1

USB_D_MINUS_RAW D2         C        C          1
                JP-USB-TOP USB_M    D-         1
                R1         2        2          1
                R3         2        2          1

USB_D_PLUS      R2         2        2          1
                U1         3        PB4(ADC2)  1

USB_D_PLUS_RAW  D1         C        C          1
                JP-USB-TOP USB_P    D+         1
                R2         1        1          1

VCC             C1         1        1          1
                C2         1        1          1
                JP-USB-TOP 5V       VBUS       1
                JP1        2        2          1
                LED1       VCC      VCC        1
                LED2       VCC      VCC        1
                R1         1        1          1
                U1         8        VCC        1

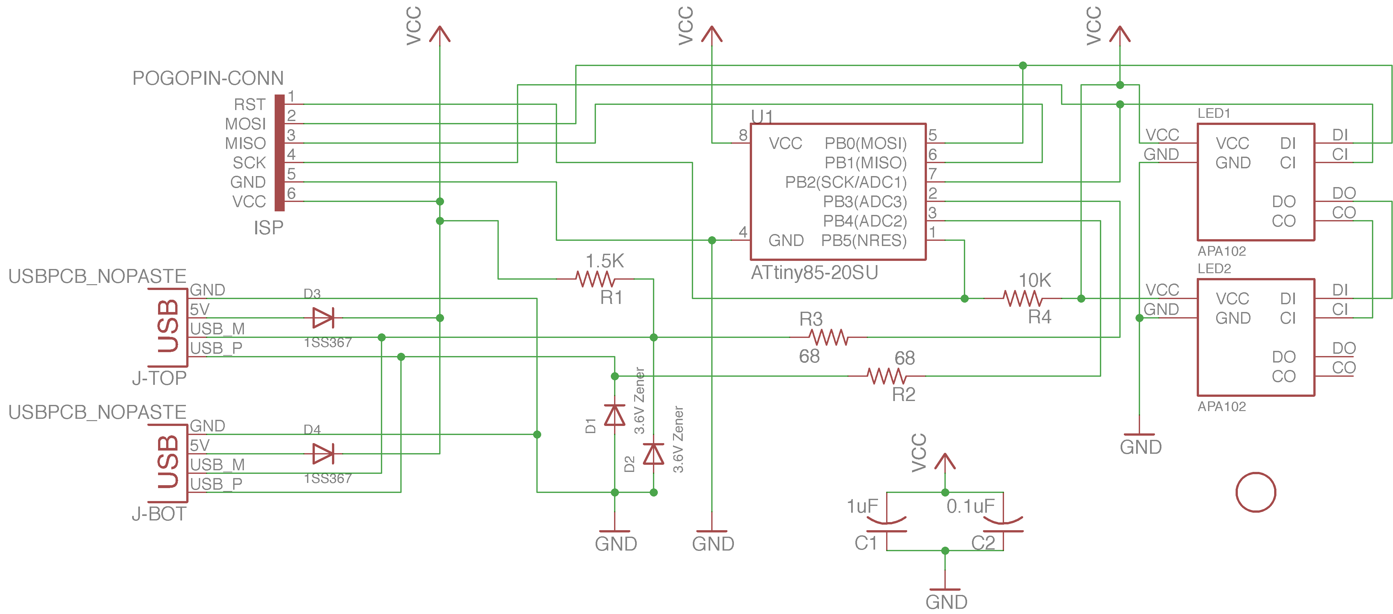
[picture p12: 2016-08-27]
hardware/mfg/production/1.0/schematic.png

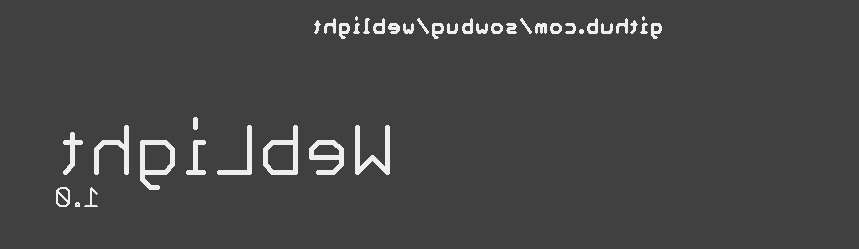
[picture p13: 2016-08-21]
hardware/mfg/production/1.0-rc1/bottom_silkscreen.png

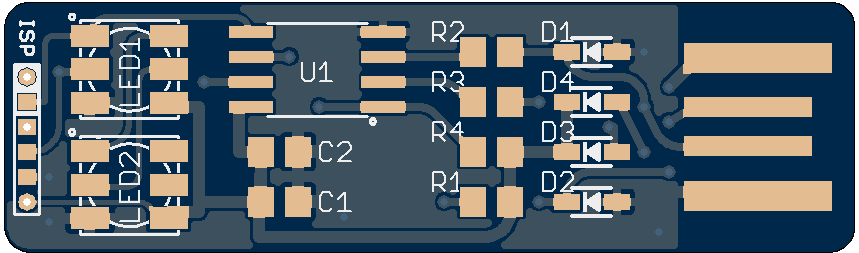
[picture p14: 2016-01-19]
hardware/mfg/production/0.9.2/top.png

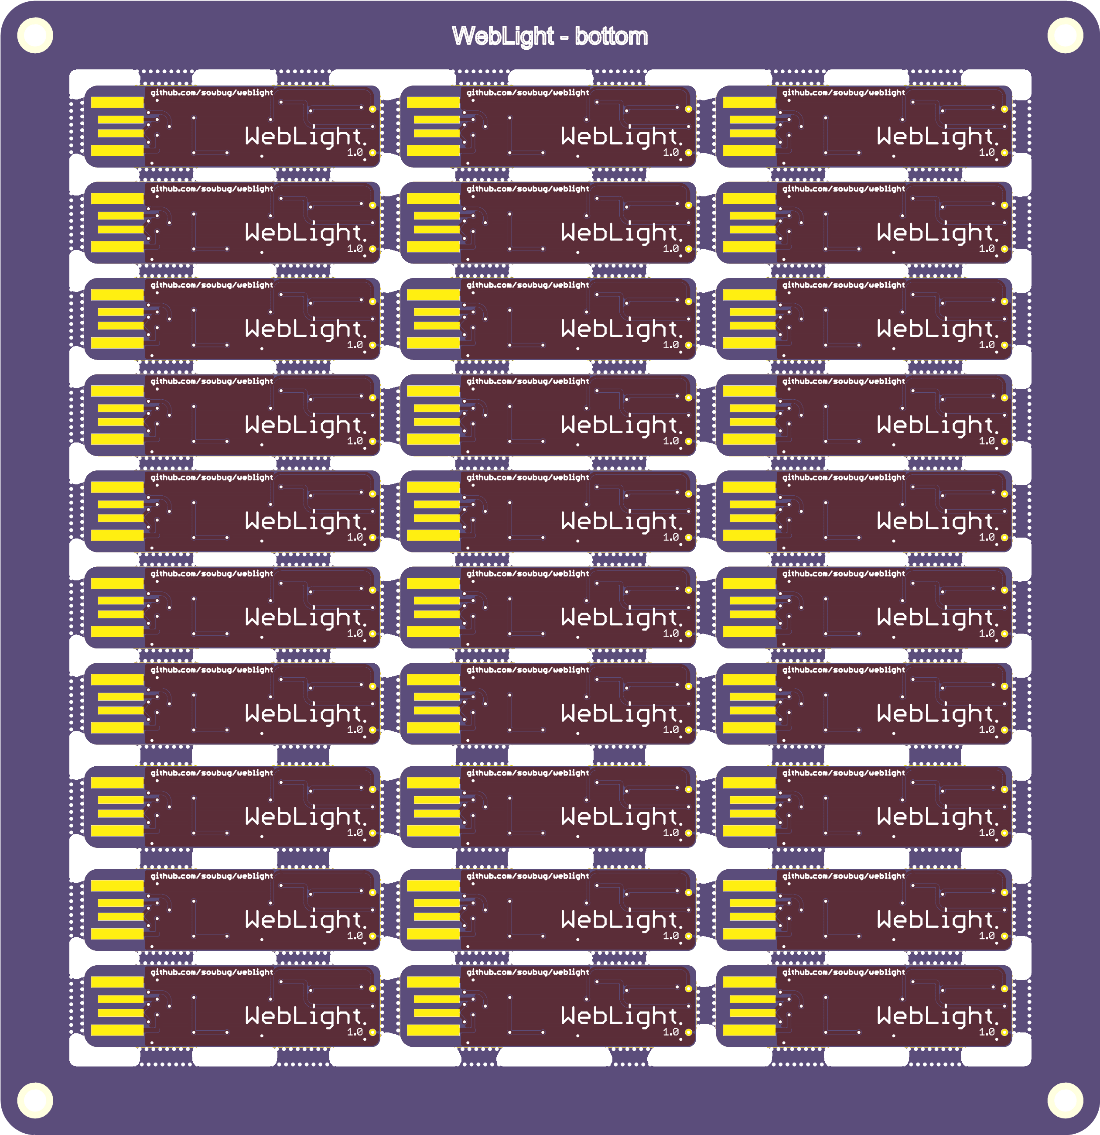
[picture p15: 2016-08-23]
hardware/mfg/production/1.0-rc1/panelized_3x10/wl_1.0_Combined_Bottom.png

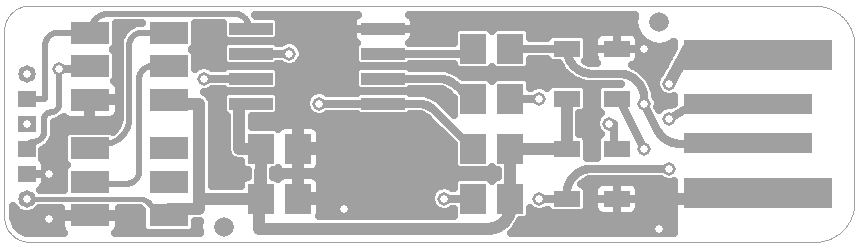
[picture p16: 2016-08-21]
hardware/mfg/production/1.0-rc1/top_copper.png

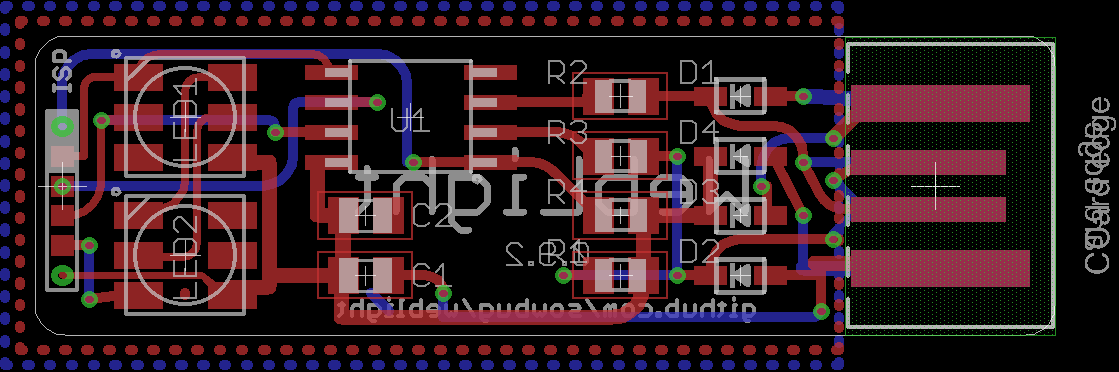
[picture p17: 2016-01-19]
hardware/mfg/production/0.9.2/board.png

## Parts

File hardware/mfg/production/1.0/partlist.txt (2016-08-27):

Partlist

Exported from weblight.sch at 8/27/16 8:51 AM

EAGLE Version 7.6.0 Copyright (c) 1988-2016 CadSoft

Assembly variant: 

Part     Value          Device                Package                              Library             Sheet

C1       1uF            C-USC0805             C0805                                rcl                 1
C2       0.1uF          C-USC0805             C0805                                rcl                 1
D1       3.6V Zener     DIODESOD-323          SOD-323                              microbuilder        1
D2       3.6V Zener     DIODESOD-323          SOD-323                              microbuilder        1
D3       1SS367         DIODESOD-323          SOD-323                              microbuilder        1
D4       1SS367         DIODESOD-323          SOD-323                              microbuilder        1
ISP      POGOPIN-CONN   POGOPIN-CONN          POGOPROG-CONN-OH-SMALLERVIAS-NOCREAM weblight            1
J-BOT    USBPCB_NOPASTE USBPCB_NOPASTE        USB-A-PCB-NOPASTE                    SparkFun-Connectors 1
J-TOP    USBPCB_NOPASTE USBPCB_NOPASTE        USB-A-PCB-NOPASTE                    SparkFun-Connectors 1
LED1     APA102         APA102                APA102                               weblight            1
LED2     APA102         APA102                APA102                               weblight            1
R1       1.5K           R-US_R0805            R0805                                rcl                 1
R2       68             R-US_R0805            R0805                                rcl                 1
R3       68             R-US_R0805            R0805                                rcl                 1
R4       10K            R-US_R0805            R0805                                rcl                 1
U1       ATtiny85-20SU  ATTINY45TINY85-20-SMT SO08-EIAJ                            SparkFun-DigitalIC  1

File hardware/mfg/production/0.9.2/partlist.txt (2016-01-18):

Partlist

Exported from weblight.sch at 1/18/16 12:39 PM

EAGLE Version 7.5.0 Copyright (c) 1988-2015 CadSoft

Assembly variant: 

Part     Value                    Device                   Package                      Library             Sheet

C1       1uF                      C-USC0805                C0805                        rcl                 1
C2       0.1uF                    C-USC0805                C0805                        rcl                 1
D1       3.6V Zener               DIODESOD-323             SOD-323                      microbuilder        1
D2       3.6V Zener               DIODESOD-323             SOD-323                      microbuilder        1
D3                                DIODESOD-323             SOD-323                      microbuilder        1
D4                                DIODESOD-323             SOD-323                      microbuilder        1
ISP      POGOPIN-CONNWITHVIAS-SMV POGOPIN-CONNWITHVIAS-SMV POGOPROG-CONN-OH-SMALLERVIAS weblight            1
J-BOT    USBPCB_NOPASTE           USBPCB_NOPASTE           USB-A-PCB-NOPASTE            SparkFun-Connectors 1
J-TOP    USBPCB_NOPASTE           USBPCB_NOPASTE           USB-A-PCB-NOPASTE            SparkFun-Connectors 1
LED1     APA102                   APA102                   APA102                       weblight            1
LED2     APA102                   APA102                   APA102                       weblight            1
R1       1.5K                     R-US_R0805               R0805                        rcl                 1
R2       68                       R-US_R0805               R0805                        rcl                 1
R3       68                       R-US_R0805               R0805                        rcl                 1
R4       10K                      R-US_R0805               R0805                        rcl                 1
U1       ATtiny85-20SU            ATTINY45TINY85-20-SMT    SO08-EIAJ                    SparkFun-DigitalIC  1

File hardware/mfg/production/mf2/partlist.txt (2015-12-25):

Partlist

Exported from weblight.sch at 12/25/15 3:44 PM

EAGLE Version 7.5.0 Copyright (c) 1988-2015 CadSoft

Assembly variant: 

Part         Value                Device                Package          Library            Sheet

C1           1uF                  C-USC0805             C0805            rcl                1
C2           0.1uF                C-USC0805             C0805            rcl                1
D1           3.6V                 DIODESOD-323          SOD-323          microbuilder       1
D2           3.6V                 DIODESOD-323          SOD-323          microbuilder       1
ISP          POGOPIN-CONNWITHVIAS POGOPIN-CONNWITHVIAS  POGOPROG-CONN-0H weblight           1
JP-USB-MICRO USB                  USB_MICRO_RIGHT       MICROUSB-RIGHT   MF_Connectors      1
LED1         APA102               APA102                APA102           weblight           1
LED2         APA102               APA102                APA102           weblight           1
R1           1.5K                 R-US_R0805            R0805            rcl                1
R2           68                   R-US_R0805            R0805            rcl                1
R3           68                   R-US_R0805            R0805            rcl                1
R4           10K                  R-US_R0805            R0805            rcl                1
U1           ATtiny85-20SU        ATTINY45TINY85-20-SMT SO08-EIAJ        SparkFun-DigitalIC 1

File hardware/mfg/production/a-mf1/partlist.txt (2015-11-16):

Partlist

Exported from weblight.sch at 11/15/15 4:49 PM

EAGLE Version 7.4.0 Copyright (c) 1988-2015 CadSoft

Assembly variant: 

Part         Value                Device                Package          Library            Sheet

C1           1uF                  C-USC0402             C0402            rcl                1
C2           0.1uF                C-USC0402             C0402            rcl                1
D1           3.6V                 DIODESOD-523          SOD-523          microbuilder       1
D2           3.6V                 DIODESOD-523          SOD-523          microbuilder       1
ICSP         POGOPIN-CONNWITHVIAS POGOPIN-CONNWITHVIAS  POGOPROG-CONN-0H weblight           1
JP-USB-MICRO USB                  USB_MICRO_RIGHT       MICROUSB-RIGHT   MF_Connectors      1
LED1         APA102               APA102                APA102           weblight           1
LED2         APA102               APA102                APA102           weblight           1
LED3         APA102               APA102                APA102           weblight           1
LED4         APA102               APA102                APA102           weblight           1
R1           1.5K                 R-US_R0402            R0402            rcl                1
R2           68                   R-US_R0402            R0402            rcl                1
R3           68                   R-US_R0402            R0402            rcl                1
R4           4.7K                 R-US_R0402            R0402            rcl                1
U1           ATtiny85-20SU        ATTINY45TINY85-20-SMT SO08-EIAJ        SparkFun-DigitalIC 1

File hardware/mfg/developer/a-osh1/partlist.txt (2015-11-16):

Partlist

Exported from weblight_developer.sch at 11/15/15 4:37 PM

EAGLE Version 7.4.0 Copyright (c) 1988-2015 CadSoft

Assembly variant: 

Part       Value                 Device                Package          Library             Sheet

C1         10uF                  C-USC0805             C0805            rcl                 1
C2         0.1uF                 C-USC0805             C0805            rcl                 1
D1         3.6V                  DIODESOD-323          SOD-323          microbuilder        1
D2         3.6V                  DIODESOD-323          SOD-323          microbuilder        1
ICSP1      AVR_SPI_PRG_62X3_LOCK AVR_SPI_PRG_62X3_LOCK 2X3_LOCK         SparkFun-Connectors 1
ICSP2      POGOPIN-CONNWITHVIAS  POGOPIN-CONNWITHVIAS  POGOPROG-CONN-0H weblight            1
JP-USB-TOP USBPCB                USBPCB                USB-A-PCB        SparkFun-Connectors 1
JP1        LED_OUT               HEADER-1X4ROUND       1X04_ROUND       microbuilder        1
LED1       APA102                APA102                APA102           weblight            1
LED2       APA102                APA102                APA102           weblight            1
R1         1.5K                  R-US_R0805            R0805            rcl                 1
R2         68                    R-US_R0805            R0805            rcl                 1
R3         68                    R-US_R0805            R0805            rcl                 1
R4         4.7K                  R-US_R0805            R0805            rcl                 1
SW1        TACT_2PIN             TACT_2PIN             TD-85XU          weblight            1
U1         ATTiny85-20SU         ATTINY45TINY85-20-SMT SO08-EIAJ        SparkFun-DigitalIC  1

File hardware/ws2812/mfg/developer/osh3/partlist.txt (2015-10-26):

Partlist

Exported from weblight_developer.sch at 10/25/2015 7:56 PM

EAGLE Version 7.4.0 Copyright (c) 1988-2015 CadSoft

Assembly variant: 

Part       Value                 Device                Package        Library             Sheet

C1         10uF                  C-USC0805             C0805          rcl                 1
C2         0.1uF                 C-USC0805             C0805          rcl                 1
D1         3.6V                  DIODESOD-323          SOD-323        microbuilder        1
D2         3.6V                  DIODESOD-323          SOD-323        microbuilder        1
D3         WS2812B               WS2812B               WS2812B        SparkFun-LED        1
D4         WS2812B               WS2812B               WS2812B        SparkFun-LED        1
JP-USB-TOP USBPCB                USBPCB                USB-A-PCB      SparkFun-Connectors 1
JP1        AVR_SPI_PRG_62X3_LOCK AVR_SPI_PRG_62X3_LOCK 2X3_LOCK       SparkFun-Connectors 1
R1         1.5K                  R-US_R0805            R0805          rcl                 1
R2         68                    R-US_R0805            R0805          rcl                 1
R3         68                    R-US_R0805            R0805          rcl                 1
R4         470                   R-US_R0805            R0805          rcl                 1
SW_RESET   BUTTON_TD-85XU        BUTTON_TD-85XU        BUTTON_TD-85XU weblight            1
U1         ATtiny85-20SU         ATTINY45TINY85-20-SMT SO08-EIAJ      SparkFun-DigitalIC  1

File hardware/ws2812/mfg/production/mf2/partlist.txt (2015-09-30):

Partlist

Exported from usb-led.sch at 9/29/2015 10:11 PM

EAGLE Version 7.4.0 Copyright (c) 1988-2015 CadSoft

Assembly variant: 

Part         Value            Device                Package        Library             Sheet

C1           10uF             C-USC0402             C0402          rcl                 1
C2           0.1uF            C-USC0402             C0402          rcl                 1
D1           3.6V             DIODESOD-523          SOD-523        microbuilder        1
D2           3.6V             DIODESOD-523          SOD-523        microbuilder        1
D3           WS2812B          WS2812B               WS2812B        SparkFun-LED        1
D4           WS2812B          WS2812B               WS2812B        SparkFun-LED        1
JP-ISP       AVR_MINI_PROGSMD AVR_MINI_PROGSMD      AVR_MINI_PROG  SparkFun-Connectors 1
JP-USB-BOT   USBPCB           USBPCB                USB-A-PCB      SparkFun-Connectors 1
JP-USB-MICRO                  USB_MICRO_RIGHT       MICROUSB-RIGHT MF_Connectors       1
JP-USB-TOP   USBPCB           USBPCB                USB-A-PCB      SparkFun-Connectors 1
R1           1.5K             R-US_R0402            R0402          rcl                 1
R2           68               R-US_R0402            R0402          rcl                 1
R3           68               R-US_R0402            R0402          rcl                 1
U1           ATtiny85-20SU    ATTINY45TINY85-20-SMT SO08-EIAJ      SparkFun-DigitalIC  1

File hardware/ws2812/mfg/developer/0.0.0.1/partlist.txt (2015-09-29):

Partlist

Exported from usb-led.brd at 9/29/15 11:15 AM

EAGLE Version 6.5.0 Copyright (c) 1988-2013 CadSoft

Assembly variant: 

Part       Value                 Package   Library             Position (inch)       Orientation

C1         10uF                  C0805     rcl                 (0.95 0.1)            R270
C2         1uF                   C0805     rcl                 (0.8 0.1)             R90
D1         3.6                   SOD-323   microbuilder        (0.65 0.35)           R90
D2         3.6                   SOD-323   microbuilder        (0.65 0.15)           R270
D3         WS2812B               WS2812B   SparkFun-LED        (1.2 0.125)           R0
D4         WS2812B               WS2812B   SparkFun-LED        (1.2 0.35)            R0
JP-ISP     AVR_SPI_PRG_62X3_LOCK 2X3_LOCK  SparkFun-Connectors (1.45 0.35)           R270
JP-USB-BOT USBPCB                USB-A-PCB SparkFun-Connectors (0.2 0.235)           MR180
JP-USB-TOP USBPCB                USB-A-PCB SparkFun-Connectors (0.2 0.235)           R0
R1         1K5                   R0805     rcl                 (0.55 0.225)          R90
R2         68                    R0805     rcl                 (0.45 0.35)           R90
R3         68                    R0805     rcl                 (0.45 0.125)          R90
U1         Tiny85-20-SMT         SO08-EIAJ SparkFun-DigitalIC  (0.875 0.325)         R270

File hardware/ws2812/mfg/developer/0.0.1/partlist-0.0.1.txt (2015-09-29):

Partlist

Exported from usb-led.sch at 9/28/2015 10:41 PM

EAGLE Version 7.4.0 Copyright (c) 1988-2015 CadSoft

Assembly variant: 

Part       Value                 Device                Package   Library             Sheet

C1         10uF                  C-USC0805             C0805     rcl                 1
C2         1uF                   C-USC0805             C0805     rcl                 1
D1         3.6                   DIODESOD-323          SOD-323   microbuilder        1
D2         3.6                   DIODESOD-323          SOD-323   microbuilder        1
D3         WS2812B               WS2812B               WS2812B   SparkFun-LED        1
D4         WS2812B               WS2812B               WS2812B   SparkFun-LED        1
JP-ISP     AVR_SPI_PRG_62X3_LOCK AVR_SPI_PRG_62X3_LOCK 2X3_LOCK  SparkFun-Connectors 1
JP-USB-BOT USBPCB                USBPCB                USB-A-PCB SparkFun-Connectors 1
JP-USB-TOP USBPCB                USBPCB                USB-A-PCB SparkFun-Connectors 1
R1         1K5                   R-US_R0805            R0805     rcl                 1
R2         68                    R-US_R0805            R0805     rcl                 1
R3         68                    R-US_R0805            R0805     rcl                 1
U1         Tiny85-20-SMT         ATTINY45TINY85-20-SMT SO08-EIAJ SparkFun-DigitalIC  1

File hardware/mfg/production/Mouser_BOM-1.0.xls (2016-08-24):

WebLight
Mouser # | Mfr. # | Manufacturer | Desc. | RoHS | Lifecycle | Customer Part # | Order Qty. | Price (USD) | Ext.: (USD)
757-1SS367H3F | 1SS367,H3F | Toshiba | Schottky Diodes & Rectifiers Sml-Signal Schottky Barrier Diode | RoHS Compliant | New At Mouser | D3, D4 | 2 | $0.21 | $0.42
588-AS08J1002ET | AS08J1002ET | Ohmite | Thick Film Resistors - SMD 0.5W 10K OHM 5% ANTI SURGE | RoHS Compliant |  | R4 | 1 | $0.06 | $0.06
843-0805J0500104KJT | 0805J0500104KJT | Syfer | Multilayer Ceramic Capacitors MLCC - SMD/SMT 50volts 0.1uF 10% | RoHS Compliant |  | C2 | 1 | $0.21 | $0.21
77-VJ0805G106KXQTBC | VJ0805G106KXQTW1BC | Vishay | Multilayer Ceramic Capacitors MLCC - SMD/SMT 0805 10uF 10volts X5R 10% | RoHS Compliant |  | C1 | 1 | $0.10 | $0.10
667-ERJ-6GEYJ152V | ERJ-6GEYJ152V | Panasonic | Thick Film Resistors - SMD 0805 1.5Kohms 5% AEC-Q200 | RoHS Compliant By Exemption |  | R1 | 1 | $0.10 | $0.10
667-ERJ-6GEYJ680V | ERJ-6GEYJ680V | Panasonic | Thick Film Resistors - SMD 0805 68ohms 5% AEC-Q200 | RoHS Compliant By Exemption |  | R2, R3 | 2 | $0.10 | $0.20
556-ATTINY85-20SU | ATTINY85-20SU | Atmel | 8-bit Microcontrollers - MCU AVR 8K FLSH 512B EE 512B SRAM ADC 5V | RoHS Compliant |  | U1 | 1 | $2.24 | $2.24
863-MM3Z3V6T1G | MM3Z3V6T1G | ON Semiconductor | Zener Diodes 3.6V 200mW | RoHS Compliant |  | D1, D2 | 2 | $0.14 | $0.28

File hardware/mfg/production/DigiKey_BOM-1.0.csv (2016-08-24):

Digi-Key Part Number | Manufacturer | Manufacturer Part Number | Customer Reference | Quantity 1 | Quantity 2 | Quantity 3 | Mfg Std Lead Time | Description | Comments | RoHS Status | Lead Free Status | REACH Status
311-1365-1-ND | YAGEO (VA) | CC0805KKX7R7BB105 | C1 | 1 | 0 | 0 | 21 Weeks | CAP CER 1UF 16V X7R 0805 | Alternate Packaging Exists | RoHS Compliant | Lead free | Unaffected Dec-2015
311-1338-1-ND | YAGEO (VA) | CC0402KRX7R7BB104 | C2 | 1 | 0 | 0 | 23 Weeks | CAP CER 0.1UF 16V X7R 0402 | Alternate Packaging Exists | RoHS Compliant | Lead free | Unaffected Dec-2015
MM3Z3V6T1GOSCT-ND | ON SEMICONDUCTOR (VA) | MM3Z3V6T1G | D1, D2 | 2 | 0 | 0 | 25 Weeks | DIODE ZENER 3.6V 300MW SOD323 | Alternate Packaging Exists | RoHS Compliant | Lead free | Unaffected Dec-2015
1SS367H3FCT-ND | TOSHIBA SEMICONDUCTOR AND STORAGE (VA) | 1SS367,H3F | D3, D4 | 2 | 0 | 0 | 10 Weeks | DIODE SCHOTTKY 10V 100MA SC76 | Alternate Packaging Exists | RoHS Compliant | Lead free | Not Available
311-1.5KARCT-ND | YAGEO (VA) | RC0805JR-071K5L | R1 | 1 | 0 | 0 | 22 Weeks | RES SMD 1.5K OHM 5% 1/8W 0805 | Alternate Packaging Exists | RoHS Compliant | Lead free | Unaffected Dec-2015
311-68ARCT-ND | YAGEO (VA) | RC0805JR-0768RL | R2, R3 | 2 | 0 | 0 | 22 Weeks | RES SMD 68 OHM 5% 1/8W 0805 | Alternate Packaging Exists | RoHS Compliant | Lead free | Unaffected Dec-2015
311-10KARCT-ND | YAGEO (VA) | RC0805JR-0710KL | R4 | 1 | 0 | 0 | 22 Weeks | RES SMD 10K OHM 5% 1/8W 0805 | Alternate Packaging Exists | RoHS Compliant | Lead free | Unaffected Dec-2015
ATTINY85-20SURCT-ND | ATMEL (VA) | ATTINY85-20SUR | U1 | 1 | 0 | 0 | 6 Weeks | IC MCU 8BIT 8KB FLASH 8SOIC | Alternate Packaging Exists | RoHS Compliant | Lead free | Unaffected Dec-2015

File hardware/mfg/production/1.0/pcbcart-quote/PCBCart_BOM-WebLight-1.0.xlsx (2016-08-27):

xxxx xxxx xxxxx xxPCS BOM
Manufacturer | Manufacturer Part Number | Designator | Qty | Description | Case | SMD ,BGA,LCC,OR TH | Top/Bottom | points | Total points | Comment
Yageo | CC0805KKX7R7BB105 | C1 | 1 | 1uF 16V Ceramic Capacitor X7R 0805 | 0805 | SMD | Top
Yageo | CC0805KRX7R7BB104 | C2 | 1 | 0.10µF 16V Ceramic Capacitor X7R 0805 | 0805 | SMD | Top
ON Semiconductor | MM3Z3V6T1G | D1, D2 | 2 | Zener Diode 3.6V 300mW ±6% Surface Mount SOD-323 | SOD-323 | SMD | Top
Toshiba | 1SS367,H3F | D3, D4 | 2 | Diode Schottky 10V 100mA Surface Mount | SOD-323 | SMD | Top
APA Electronic Co | APA102C | LED1, LED2 | 2 | SUPER LED APA-102C RGB FULL COLOR 5050 | 5050 | SMD | Top
Yageo | RC0805JR-071K5L | R1 | 1 | RES SMD 1.5K OHM 5% 1/8W 0805 | 0805 | SMD | Top
Yageo | RC0805JR-0768RL | R2, R3 | 2 | RES SMD 68 OHM 5% 1/8W 0805 | 0805 | SMD | Top
Yageo | RC0805JR-0710KL | R4 | 1 | RES SMD 10K OHM 5% 1/8W 0805 | 0805 | SMD | Top
Atmel | ATTINY85-20SUR | U1 | 1 | AVR AVR® ATtiny Microcontroller IC 8-Bit 20MHz 8KB (4K x 16) FLASH 8-SOIC | 8-SOIC | SMD | Top

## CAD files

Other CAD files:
hardware/mfg/developer/a-seeed1/weblight_developer-tcream.dxf
hardware/mfg/production/0.9.3/weblight-tcream.dxf
hardware/mfg/production/0.9.3/weblight-bcream.dxf

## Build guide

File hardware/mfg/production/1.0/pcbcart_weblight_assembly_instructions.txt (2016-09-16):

Atmel AVR ATTiny85
https://github.com/sowbug/weblight
https://github.com/sowbug/weblight/blob/master/firmware/hex/weblight-full-1.0.hex

FUSE
====

avrdude -p attiny85 -U lfuse:w:0xe1:m -U hfuse:w:0xdd:m -U efuse:w:0xfe:m

PROGRAMMING
===========

$ shasum firmware/hex/weblight-full-1.0.hex
b8342c13ef73ea37cf15128e2ef9a78e56985bfe  firmware/hex/weblight-full-1.0.hex

avrdude -p attiny85 -B 1 -U flash:w:firmware/hex/weblight-full-1.0.hex:i

TEST
====

1. Assemble board.
2. Insert board in USB power source.
3. See red, green, blue cycle on both LED.
4. Success!

See video of smoke test at https://youtu.be/knSyfHsJjvY

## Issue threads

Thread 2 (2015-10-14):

Connectors on back of board cause short

sowbug, 2015-10-14:
Either add diodes or remove the feature.

sowbug, 2015-10-26:
Removed bottom connector.

Closed 2015-10-26.

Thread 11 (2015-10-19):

Capacitive touch sensor

sowbug, 2015-10-19:
See https://github.com/cpldcpu/TinyTouchLib

sowbug, 2015-11-02:
Given that the touch library has yet more stringent interrupt requirements, I've decided a touch sensor is out of scope for this project. The use case was acknowledging an alert.

Closed 2015-11-02.

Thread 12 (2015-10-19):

Space for more LEDs on back

sowbug, 2015-10-19:
Depends on use case. If they're covered, then they go to waste.

sowbug, 2015-10-26:
Added to production board. Decided not to implement for developer board.

Closed 2015-10-26.

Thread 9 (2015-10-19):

Behavior when disconnected

sowbug, 2015-10-19:
EEPROM configuration could tell board to behave differently when plugged only into power source (without a data connection).

sowbug, 2016-01-18:
This is good enough as-is. If you save a program to EEPROM, it runs on startup.

Closed 2016-01-18.

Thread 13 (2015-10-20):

Fix interference between WS2812 library and V-USB

sowbug, 2015-10-20:
V-USB really doesn't want anyone else using interrupts. Switch to micronucleus 2.0?

sowbug, 2015-10-31:
Might need to do this by switching light to APA102C. It's hard to have two timing-sensitive components coexist peacefully.

Bluebie, 2015-11-01:
ws2812 LEDs do not require you update then with a specific frequency. They can be send a colour and they will internally hold that rgb value with their own internal free running PWM controller. I'm a bit confused why weblight even uses interrupts to drive this.

You might like to look at littlewire.cc - it supports outputting to large ws2812 strands and runs on interrupt v-usb on attiny85. Your StatusBlink function in led_control.c might give you some trouble though, as those long delay loops will block your main event loop for a long while and could be disruptive to USB. Generally if you're going to block your event loop for more than about 50ms you really need to be calling usbPoll in your delay loop and using timers, like this: https://github.com/digistump/DigisparkArduinoIntegration/blob/master/libraries/DigisparkUSB/DigiUSB.cpp#L96

Bluebie, 2015-11-01:
something of note: the way littlewire deals with timing is similar to micronucleus in a way - it only ever sends colours to the leds in response to a usb command. because usb only updates at 1khz, when you recieve a command you know you have about 1000ns to do whatever you like without getting any usb-related interrupts messing up your timing. turns out that's plenty of time to update some LEDs. If for some reason you want to persistently be updating them (animating them device side?) you could perhaps do that work at the end of the usb interrupt handler? or set a flag that the interrupt handler resets which gives the event loop permission to update the LEDs again? that way you'd have a piece of code running at 1khz with time to mess around uninterrupted, even when no commands are being sent. USB idles with a 1khz pulse that acts as a sort of keep alive and timing signal.

sowbug, 2015-11-01:
Thank you for your insight, @Bluebie! I misspoke in the original issue description. What I meant to say is that V-USB doesn't want anyone else messing around with the interrupt system. What I observed in my initial experiments was that if I updated the WS2812s too often (exactly the device-side animation you're speculating about), I'd start to see I/O errors with USB -- sometimes a string descriptor request would fail, etc. I wasn't updating the lights in a timer or an interrupt routine, but I was updating them frequently.

I noticed that the I/O errors happened more frequently if I updated both LEDs rather than just one, and this was the clue I needed to figure out that because the WS2812 library called cli() before doing its business, it was stealing real-time code execution that micronucleus needed, which was messing around with the USB servicing. (Understand that at this point I couldn't rule out anything -- memory smasher, bad hardware design on my prototype board, misusing the V-USB code, etc., so this was just one of several theories what was wrong.)

For a while I simply left interrupts enabled in the WS2812 code, which definitely fixed the I/O errors, but it made light updates unreliable at worst, and flickery at best (all as expected).

I ended up separating the concept of setting the LED colors in the RGB SRAM buffer from sending that buffer to the physical LEDs, and then throwing the sending code into USB_POST_TX_HOOK (https://github.com/sowbug/weblight/blob/master/firmware/usbconfig.h#L145), reasoning that if USB was a request-response model, which I think it is for the kinds of data I'm using, then I was likely to be able to briefly shut off interrupts and run the WS2812 code right after sending my responses. So far, this has worked quite well, but I didn't know enough about USB to feel that this was a robust approach.

If I'm reading your suggestions correctly, then my current solution might be reasonable. I'll think about your idea of updating in the main event loop after the interrupt has run -- that's similar in principle to what I had done, but it feels better because I know it'll fire at 1kHz.

(BTW StatusBlink() is only for debugging -- basically "yes this line of code ran!" -- and at that point I'm no longer caring about anything else. But it'd be very cool to make even that work, and I'll experiment with the DigiUSB method of delaying safely.)

Thanks again!

sowbug, 2015-11-01:
More on USB_POST_TX_HOOK, which might have had you saying "huh?":

https://github.com/sowbug/weblight/commit/db749fba1cc9da55c094c4623d357246b030b4ab

Bluebie, 2015-11-01:
oh the request-response thing: that's correct. I'm not sure about higher speed versions of USB, but for low speed devices like these, USB has a very strict architecture. Devices never initiate communication. USB "interrupts" work by setting a flag which the host reads as part of that 1khz polling message, then if the host sees that, it should request the interrupt message on it's own schedule.

The only catch with using that 1000kz polling signal to drive lighting updates is that if the host goes to sleep, the polling will stop, so your animation could freeze. If you wanted to be super fancy you could detect that with a timer and fade the lights out when the computer goes to sleep or switch to using an internal timer to drive the animation till the host wakes up.

sowbug, 2015-11-01:
Ugh, sleep. You're many steps ahead of me (which is great because you're saving me design/debugging time). So I guess the logic could be something like this:

```
// Somewhere in main loop
if (animation_timer_has_expired) {
  if (host_is_asleep) {
    animate_lights_and_reset_timer();
  } else {
    if (vusb_interrupt_ran) {
      animate_lights_and_reset_timer();
    }
  }
}
// Reset this each time through loop because when host is awake,
// we want to update lights only ASAP after the interrupt.
vusb_interrupt_ran = false;
```

I could probably tighten up that logic, but I think this carries out what you're saying.

sowbug, 2015-11-02:
This is about as fixed as it needs to be. As we add more features, we will figure out how to fit them into the small time slice after the USB host heartbeat.

Bluebie, 2015-11-02:
pseudocode looks reasonable to me. 👍

Closed 2015-11-02.

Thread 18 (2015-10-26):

Switch to real VID/PID

sowbug, 2015-10-26:
See http://wiki.openmoko.org/wiki/USB_Product_IDs for more. Have applied. Likely to be 0x1d50/0x60e2.

sowbug, 2015-10-27:
https://github.com/sowbug/pidcodes.github.com/commit/68198cfea58ad41a04108fe482d2d69c3189ea19

0x1209/0xa800

Closed 2015-10-27.

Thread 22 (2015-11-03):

Handle HSV/HSB in addition to RGB

sowbug, 2015-11-03:
https://en.wikipedia.org/wiki/HSL_and_HSV

https://github.com/pololu/apa102-arduino/blob/master/APA102.h

sowbug, 2015-12-24:
This concept doesn't need to be exposed in the firmware. The client can do conversions on the PC side.

However, transitions should happen in some space other than RGB. See http://www.stuartdenman.com/improved-color-blending, http://rileyjshaw.com/blog/hue-angle-transitions/ for discussion.

Closed 2015-12-25.

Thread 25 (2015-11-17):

Chrome WebUSB can't handle PROGMEM descriptors

sowbug, 2015-11-17:
For some strange reason, Chrome won't recognize a device after this patch has been applied:

https://github.com/sowbug/weblight/commit/c73be82dbb46d73e690398a7780dd4b102112e7c

Other USB tools seem to handle it just fine, and WinUSB descriptors work fine on Windows. What's going on? @reillyeon, any idea?

sowbug, 2015-11-17:
@reillyeon

reillyeon, 2015-11-17:
Not sure but I can throw my USB analyzer at it. Your change looks isomorphic to the existing WinUSB code so it should be working.

sowbug, 2015-12-07:
I just dropped off a green board on your desk. It's flashed with https://github.com/sowbug/weblight/commit/c73be82dbb46d73e690398a7780dd4b102112e7c and thus demonstrates the bug.

reillyeon, 2015-12-07:
It appears that both WebUSB control transfers time out. The first one is sent to the device but no response is received.

sowbug, 2015-12-25:
Still investigating.

Closed 2015-12-25.

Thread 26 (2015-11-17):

Change production board form factor to match tealight

sowbug, 2015-11-17:
Plastic tealight holders are perfect for containing the board and spreading the light. As long as they can be drilled for the USB connection, they'll work nicely.

http://www.aliexpress.com/item/Flicker-12PCS-Rechargeable-LED-Tealight-with-Plastic-Cup-and-Charging-Base-Flameless-LED-Candle-romantic-birthday/32463000158.html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,searchweb201644_5,searchweb201560_9

https://en.wikipedia.org/wiki/Tealight "[A] common type of tea-light is circular, approximately 38mm diameter by 16mm high, with white unscented wax."

sowbug, 2015-11-17:
As long as the length allows the board to fit in the area of a tealight, it can stay mostly rectangular.

sowbug, 2015-12-26:
The current production board works in this form factor. I'm not going to try harder at this point to customize the board layout for a particular container.

Closed 2015-12-26.

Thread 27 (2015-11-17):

Add candlelight sequence

sowbug, 2015-11-17:

sowbug, 2015-12-25:
Not-too-beautiful version at https://github.com/sowbug/weblight/commit/543643a19742a1994996eac7b74189d05757adcd. It has the right idea that full brightness is the most common and flickers are rare, but it's missing the right feeling.

See https://cpldcpu.wordpress.com/2013/12/08/hacking-a-candleflicker-led/ and http://timbartlett.net/ledcandle/ for more ideas. I might do a 16-level CLUT with yellow fading to orange and then red, with the biased RNG indexing into it.

Closed 2015-12-25.

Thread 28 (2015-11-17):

LEDs should be physically centered on board

sowbug, 2015-11-17:

sowbug, 2015-12-26:
Done in https://github.com/sowbug/weblight/commit/4504d614f5c94444537d5ad37078f3c8612a1cc7

Closed 2015-12-26.

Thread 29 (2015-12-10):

Add demo/test mode

sowbug, 2015-12-10:
On initial flash from `make flash_eeprom`, the board should be in demo mode, where it cycles through the colors in a way that makes it apparent to a QA person that the board is physically sound from MCU to LEDs.

Phase two of the test will be using `wlctl` to take it out of demo mode, which proves that the remaining circuitry (USB to MCU) is also sound.

sowbug, 2015-12-25:
This is done. `make factory/factory_mp` will burn in the demo sequence, which can be overwritten with `wlctl`, and sending any COLOR command will stop the sequencer.

Closed 2015-12-25.

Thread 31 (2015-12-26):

Tracking issue for people interested in a copy of the board

sowbug, 2015-12-26:
Star the repo and subscribe to this issue if you want to be notified if/when a manufacturing run of WebLights happens.

dbdaf, 2019-03-09:
I’d like to have one！

sowbug, 2019-03-22:
> I’d like to have one！

Email me your shipping address and I will drop a couple in the mail for you. My email address is in the commit logs of this project.

Closed 2016-11-25.

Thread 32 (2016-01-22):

The production board is too wide

sowbug, 2016-01-22:
Sigh. The switch to connectorless should have been accompanied by a resizing of the board. Maybe next time you'll do that before doing an expensive PCB run.

Closed 2016-01-22.

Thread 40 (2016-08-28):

Invent way to stamp factory-programmed devices with serial number

sowbug, 2016-08-28:
The `make factory_mp` method is fine for quickly producing boards with an AVR ISP. But if you're ordering preprogrammed ATTiny85 chips from a supplier like Mouser or DigiKey, then that's not going to work because each chip is bit-for-bit identical, and WebLight assumes that each device has a unique serial number.

The solution is probably going to involve defining a blank serial number and then teaching `wlctl` to stick a valid serial number into the EEPROM. This means, unfortunately, that there will be a manual step after factory manufacture to imprint the serial number on each device.

sowbug, 2016-11-25:
Fixed in 755089ed

Closed 2016-11-25.

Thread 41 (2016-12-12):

WebLight demo page doesn't handle multiple devices at once

sowbug, 2016-12-12:
Plug in two WebLights that are configured to connect to https://sowbug.github.io/weblight/. If necessary, pair them. Note that the two control divs on the page have the same serial number, and they control only one of the two devices.

I've skimmed https://github.com/sowbug/weblight/blob/gh-pages/weblight.js and don't see anything obviously wrong. I know this used to work. Has anything changed?

reillyeon, 2016-12-14:
Confirmed, something weird is happening.

Closed 2017-09-07.

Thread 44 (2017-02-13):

Allow individual control of LEDs

sowbug, 2017-02-13:
The hardware has the capability of individual LED control (not just the RGB composition, but each lamp assembly). Please pipe that capability through to the protocol/tools.

samccone, 2017-12-31:
I went ahead and made a patch here to support it
https://github.com/samccone/weblight/commit/98ec34917785baf40ee255ea5648405e41cb5d03

This change however is somewhat breaking to the API as old 3 byte calls will now set no colors.
Thoughts? (if we do not care about backwards compat happy to open a PR with the existing code).

Thanks!

binaryf0x, 2017-12-31:
Unless we bump the device version so that the web app can tell the difference between the two firmware versions we shouldn't do it this way because there are lots of existing devices out there that expect the old command. I don't see your patch modifying the JavaScript code. Have you tested that with this change?

reillyeon, 2017-12-31:
Have you tested this with the web app? I don't seen an update to the JavaScript code.

If we have to update the protocol for this we could bump the device version (bcdDevice in the descriptor) so that the app can detect it and send the right command.

samccone, 2017-12-31:
Oh I made a new webapp locally that does a few extra things, if you are OK with this patch I can update the existing webapp to use this new protocol.

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

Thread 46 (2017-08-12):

Program firmware from USB?

auchenberg, 2017-08-12:
Is it possible to program the firmware from the USB port?

```
avrdude -c usbtiny -p attiny85 -B 1 -U lfuse:w:0xe1:m -U hfuse:w:0xdd:m -U efuse:w:0xfe:m -B 20
avrdude: Error: Could not find USBtiny device (0x1781/0xc9f)

avrdude done.  Thank you.
```

sowbug, 2017-08-12:
Not the bootloader. Only the application. The bootloader enables
application programming by USB.

You will need some kind of AVR ISP programmer to bootstrap. It's possible
to make one with an Arduino and a bunch of wires.

On Sat, Aug 12, 2017, 2:50 PM Kenneth Auchenberg <notifications@github.com>
wrote:

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

auchenberg, 2017-08-13:
Alrighty, I'll give it a try!

sowbug, 2017-08-13:
@auchenberg if you have somehow come across an unprogrammed board, it might be easier if I send you a couple programmed ones. Let me know.

auchenberg, 2017-08-13:
@sowbug I got a big box from you guys per https://github.com/sowbug/weblight/issues/45. Just did't realize, before now, that I had to build my own programmer before being able to program then.

I'll figure something out ;)

sowbug, 2017-08-14:
Aha. Those must have been from a different team. Multiple teams have
manufactured them. Usually when I send them out I've already put the
bootloader on them.

When you plugged one in the first time, did it blink extremely bright
red/green/blue? If so, then it might have a working bootloader already on
it. Did you follow the instructions in the README (`make clean upload` is
the important step)? If you get that far, and it works, then you don't need
the ISP.

On Sun, Aug 13, 2017, 4:34 PM Kenneth Auchenberg <notifications@github.com>
wrote:

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

auchenberg, 2017-08-14:
Ah, yes they are flashing RGB when plugged in.

When running `make clean upload` I'll get:
```
 make clean upload
rm -f *.hex *.lst *.obj *.o main.cof main.list \
              main.map main.eep.hex main.elf *.o usbdrv/*.o \
              main.s usbdrv/usbdrv.s
avr-gcc -Wall -Os -DF_CPU=16500000       -Iusbdrv -I. -DDEBUG_LEVEL=0 -mmcu=attiny85 -ffunction-sections -Wl,-gc-sections -DLED_COUNT=2 -DDEVICE_VERSION_MAJOR=1 -DDEVICE_VERSION_MINOR=0 -c usbdrv/usbdrv.c -o usbdrv/usbdrv.o
avr-gcc -Wall -Os -DF_CPU=16500000       -Iusbdrv -I. -DDEBUG_LEVEL=0 -mmcu=attiny85 -ffunction-sections -Wl,-gc-sections -DLED_COUNT=2 -DDEVICE_VERSION_MAJOR=1 -DDEVICE_VERSION_MINOR=0 -x assembler-with-cpp -c usbdrv/usbdrvasm.S -o usbdrv/usbdrvasm.o
avr-gcc -Wall -Os -DF_CPU=16500000       -Iusbdrv -I. -DDEBUG_LEVEL=0 -mmcu=attiny85 -ffunction-sections -Wl,-gc-sections -DLED_COUNT=2 -DDEVICE_VERSION_MAJOR=1 -DDEVICE_VERSION_MINOR=0 -c main.c -o main.o
avr-gcc -Wall -Os -DF_CPU=16500000       -Iusbdrv -I. -DDEBUG_LEVEL=0 -mmcu=attiny85 -ffunction-sections -Wl,-gc-sections -DLED_COUNT=2 -DDEVICE_VERSION_MAJOR=1 -DDEVICE_VERSION_MINOR=0 -c osccal.c -o osccal.o
avr-gcc -Wall -Os -DF_CPU=16500000       -Iusbdrv -I. -DDEBUG_LEVEL=0 -mmcu=attiny85 -ffunction-sections -Wl,-gc-sections -DLED_COUNT=2 -DDEVICE_VERSION_MAJOR=1 -DDEVICE_VERSION_MINOR=0 -c app.c -o app.o
avr-gcc -Wall -Os -DF_CPU=16500000       -Iusbdrv -I. -DDEBUG_LEVEL=0 -mmcu=attiny85 -ffunction-sections -Wl,-gc-sections -DLED_COUNT=2 -DDEVICE_VERSION_MAJOR=1 -DDEVICE_VERSION_MINOR=0 -c eeprom.c -o eeprom.o
avr-gcc -Wall -Os -DF_CPU=16500000       -Iusbdrv -I. -DDEBUG_LEVEL=0 -mmcu=attiny85 -ffunction-sections -Wl,-gc-sections -DLED_COUNT=2 -DDEVICE_VERSION_MAJOR=1 -DDEVICE_VERSION_MINOR=0 -c led_control.c -o led_control.o
avr-gcc -Wall -Os -DF_CPU=16500000       -Iusbdrv -I. -DDEBUG_LEVEL=0 -mmcu=attiny85 -ffunction-sections -Wl,-gc-sections -DLED_COUNT=2 -DDEVICE_VERSION_MAJOR=1 -DDEVICE_VERSION_MINOR=0 -c webusb.c -o webusb.o
avr-gcc -Wall -Os -DF_CPU=16500000       -Iusbdrv -I. -DDEBUG_LEVEL=0 -mmcu=attiny85 -ffunction-sections -Wl,-gc-sections -DLED_COUNT=2 -DDEVICE_VERSION_MAJOR=1 -DDEVICE_VERSION_MINOR=0 -c light_apa102.c -o light_apa102.o
avr-gcc -Wall -Os -DF_CPU=16500000       -Iusbdrv -I. -DDEBUG_LEVEL=0 -mmcu=attiny85 -ffunction-sections -Wl,-gc-sections -DLED_COUNT=2 -DDEVICE_VERSION_MAJOR=1 -DDEVICE_VERSION_MINOR=0 -c sequencer.c -o sequencer.o
avr-gcc -Wall -Os -DF_CPU=16500000       -Iusbdrv -I. -DDEBUG_LEVEL=0 -mmcu=attiny85 -ffunction-sections -Wl,-gc-sections -DLED_COUNT=2 -DDEVICE_VERSION_MAJOR=1 -DDEVICE_VERSION_MINOR=0 -o main.elf usbdrv/usbdrv.o usbdrv/usbdrvasm.o main.o osccal.o app.o eeprom.o led_control.o webusb.o light_apa102.o sequencer.o
rm -f main.hex main.eep.hex
avr-objcopy -j .text -j .data -O ihex main.elf main.hex
avr-size main.hex
   text    data     bss     dec     hex filename
      0    6458       0    6458    193a main.hex
../commandline/wlctl --reset
micronucleus --run main.hex
> Please plug in the device ...
> Press CTRL+C to terminate the program.
^Cmake: *** [upload] Interrupt: 2
```

And when using the CLI `./commandline/wlctl 800000` I'm getting `No device is connected (1209/a800)`

This seems like a generel MacOS problem, right?

sowbug, 2017-08-14:
Yes, I've seen that before on MacOS. I have much better luck directly
connecting to a non-USB 3.0 port with no hub in between. On some USB 2.0
hubs, only certain ports connect reliably. I remember that libusb was
troublesome as well; I think that with a newer version of OSX it broke and
I had to compile it from recent source.

Linux is far more reliable, though you do have to set up udev.

On Sun, Aug 13, 2017 at 10:05 PM Kenneth Auchenberg <
notifications@github.com> wrote:

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

auchenberg, 2017-08-21:
Ah, a bit hard to find a non USB 3.0 port on a Macbook with just USB-C :/

I'll try from a Windows machine or doing a boot to Ubunto.

Closed 2017-08-13.

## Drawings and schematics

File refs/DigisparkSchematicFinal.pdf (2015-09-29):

## MC78M05BDTRKG

## GND

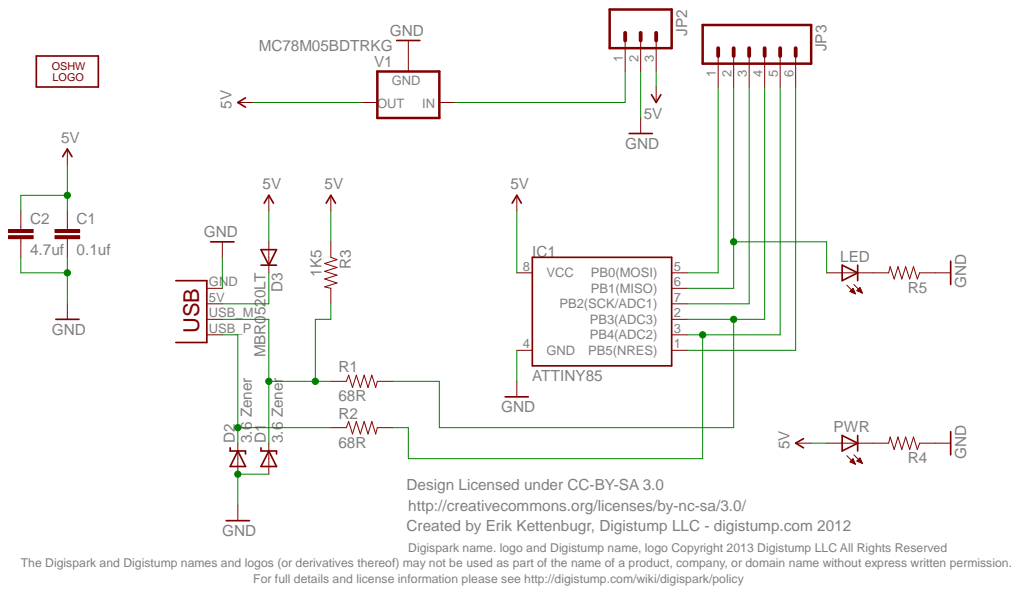
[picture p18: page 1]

Design Licensed under CC-BY-SA 3.0
http://creativecommons.org/licenses/by-nc-sa/3.0/
Created by Erik Kettenbugr, Digistump LLC - digistump.com 2012
Digispark name. logo and Digistump name, logo Copyright 2013 Digistump LLC All Rights Reserved

The Digispark and Digistump names and logos (or derivatives thereof) may not be used as part of the name of a product, company, or domain name without express written permission.

For full details and license information please see http://digistump.com/wiki/digispark/policy

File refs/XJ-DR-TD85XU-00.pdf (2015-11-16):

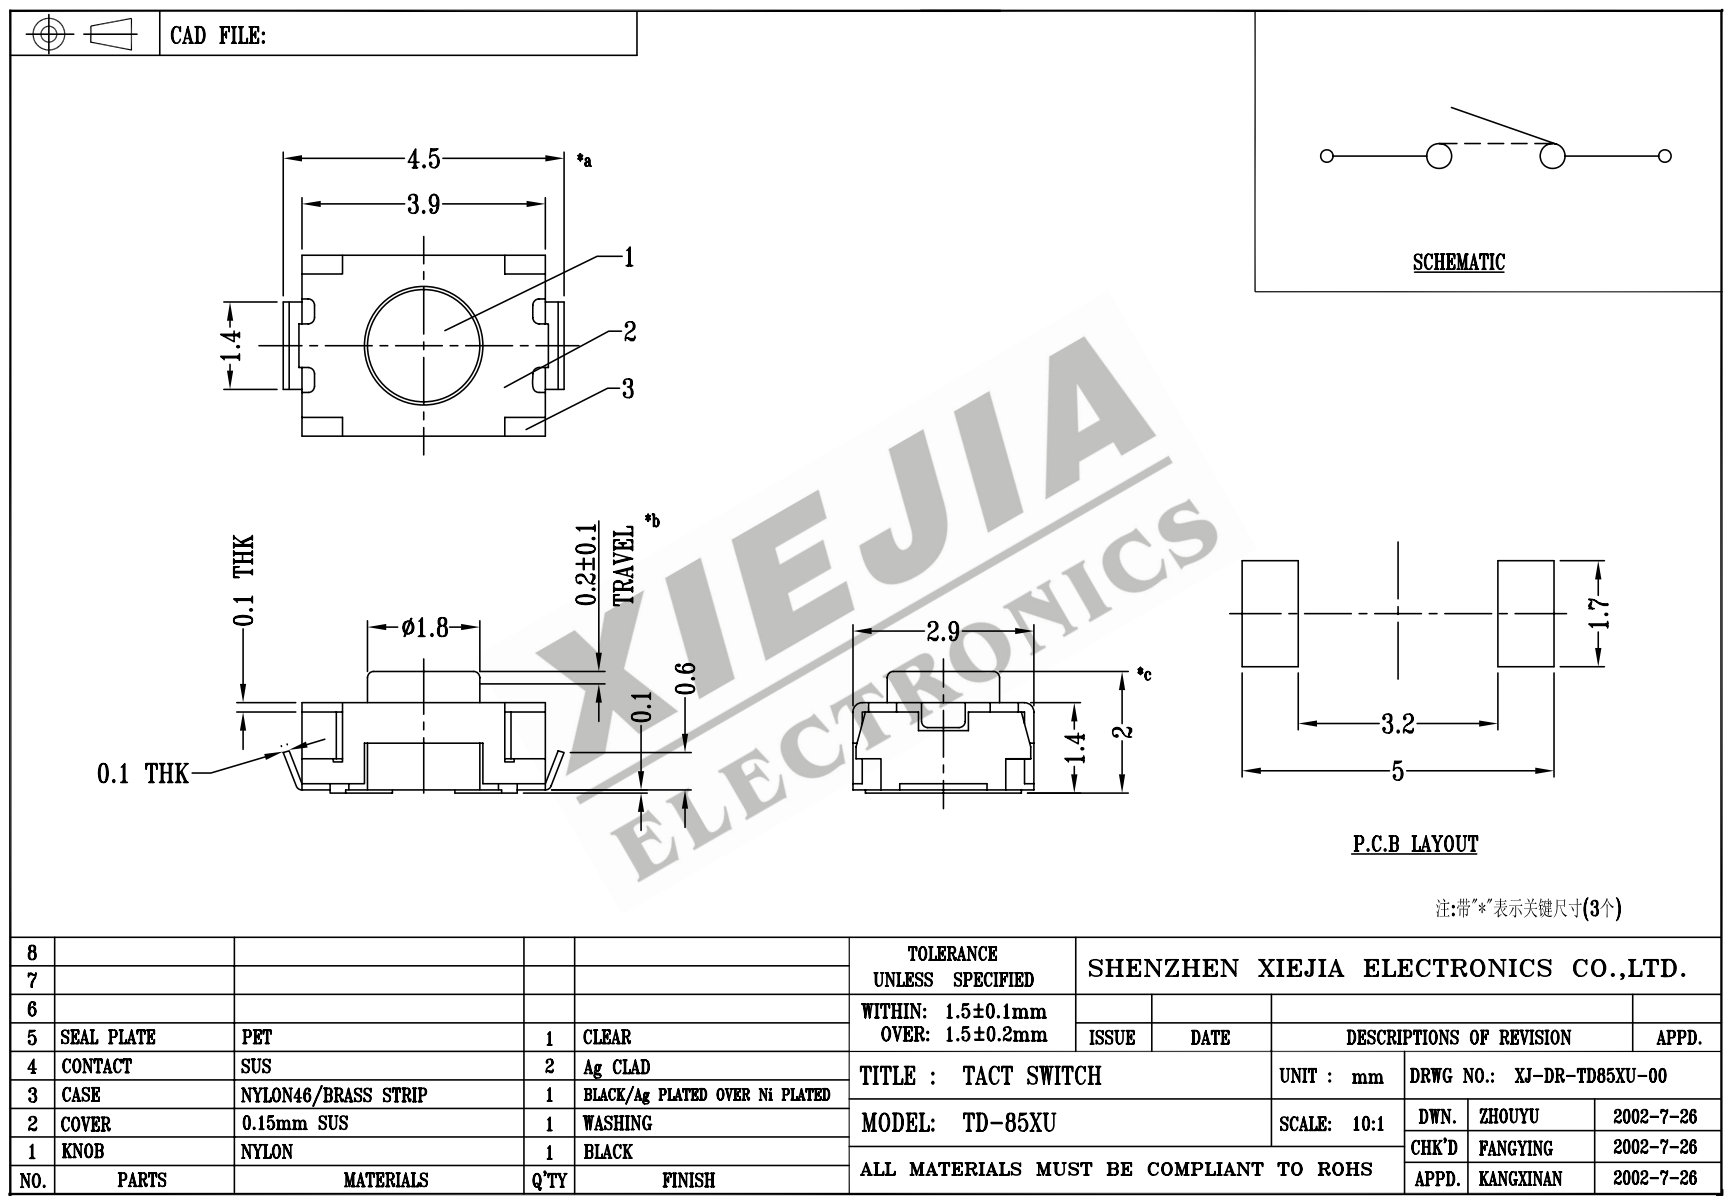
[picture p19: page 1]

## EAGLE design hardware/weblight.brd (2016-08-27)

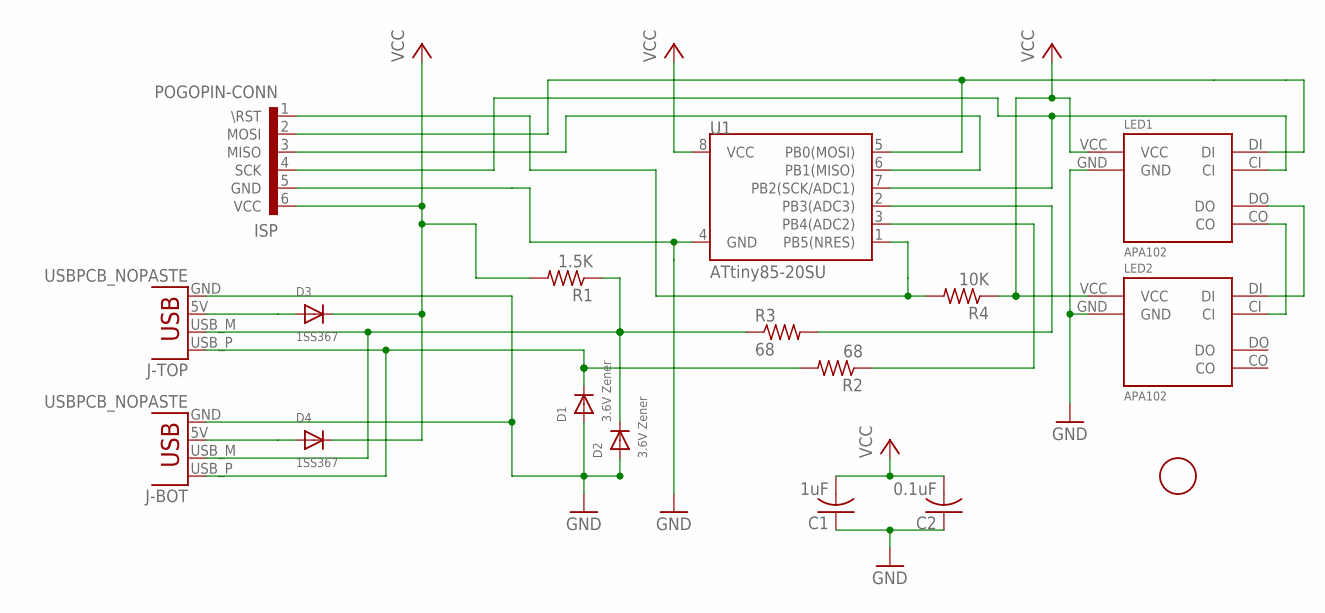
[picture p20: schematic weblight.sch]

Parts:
C1: 1uF; C0805
C2: 0.1uF; C0805
D1, D2: 3.6V Zener; SOD-323
D3, D4: 1SS367; SOD-323
FID1: FIDUCIAL; FIDUCIAL_1MM
ISP: POGOPIN-CONN; POGOPROG-CONN-OH-SMALLERVIAS-NOCREAM
J-BOT: USBPCB_NOPASTE; USB-A-PCB-NOPASTE
J-TOP: USBPCB_NOPASTE; USB-A-PCB-NOPASTE
LED1, LED2: APA102
R1: 1.5K; R0805
R2, R3: 68; R0805
R4: 10K; R0805
U1: ATtiny85-20SU; SO08-EIAJ

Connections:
5V-BOT: D4.A, J-BOT.5V (VBUS)
5V-TOP: D3.A, J-TOP.5V (VBUS)
CLK_1/SCK: ISP.4 (SCK), LED1.CI, U1.7 (PB2(SCK/ADC1))
CLK_2: LED1.CO, LED2.CI
DIN_1/MOSI: ISP.2 (MOSI), LED1.DI, U1.5 (PB0(MOSI))
DIN_2: LED1.DO, LED2.DI
GND: C1.1, C2.1, D1.A, D2.A, ISP.5 (GND), J-BOT.GND, J-TOP.GND, LED1.GND, LED2.GND, U1.4 (GND)
MISO: ISP.3 (MISO), U1.6 (PB1(MISO))
N_RESET: ISP.1 (\RST), R4.2, U1.1 (PB5(NRES))
USB_D_MINUS: R3.2, U1.2 (PB3(ADC3))
USB_D_MINUS_RAW: D2.C, J-BOT.USB_M (D-), J-TOP.USB_M (D-), R1.1, R3.1
USB_D_PLUS: R2.1, U1.3 (PB4(ADC2))
USB_D_PLUS_RAW: D1.C, J-BOT.USB_P (D+), J-TOP.USB_P (D+), R2.2
VCC: C1.2, C2.2, D3.C, D4.C, ISP.6 (VCC), LED1.VCC, LED2.VCC, R1.2, R4.1, U1.8 (VCC)

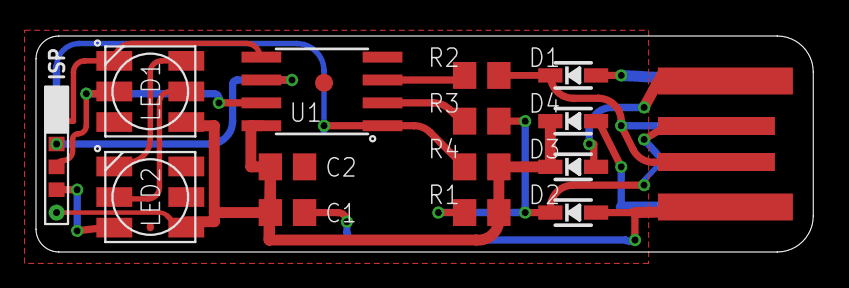
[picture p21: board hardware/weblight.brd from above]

Board: 2 copper layers, 43.2 x 12.0 mm, 17 parts (1 on the bottom side), 14 nets.

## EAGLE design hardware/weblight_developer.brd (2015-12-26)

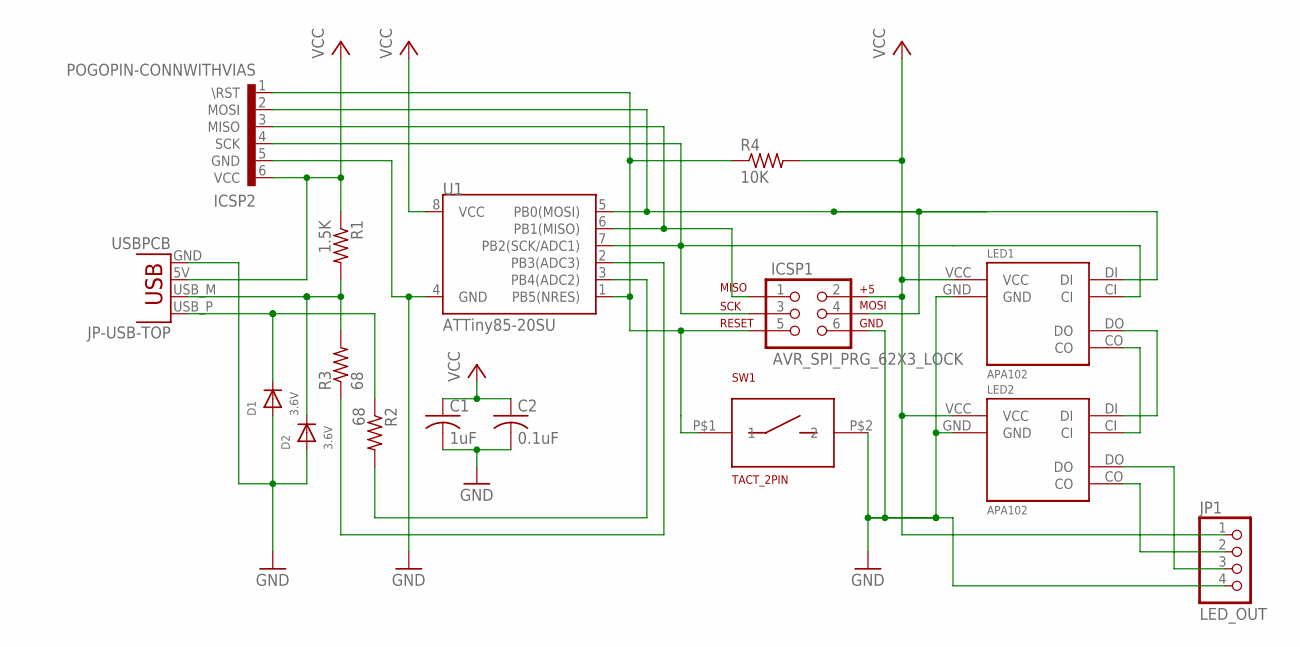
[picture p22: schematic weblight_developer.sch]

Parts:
C1: 1uF; C0805
C2: 0.1uF; C0805
D1, D2: 3.6V; SOD-323
ICSP1: AVR_SPI_PRG_62X3_LOCK; 2X3_LOCK
ICSP2: POGOPIN-CONNWITHVIAS; POGOPROG-CONN-0H
JP1: LED_OUT; 1X04_ROUND
JP-USB-TOP: USBPCB; USB-A-PCB
LED1, LED2: APA102
R1: 1.5K; R0805
R2, R3: 68; R0805
R4: 10K; R0805
SW1: TACT_2PIN; TD-85XU
U1: ATTiny85-20SU; SO08-EIAJ

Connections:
CLK_1/SCK: ICSP1.3, ICSP2.4 (SCK), LED1.CI, U1.7 (PB2(SCK/ADC1))
CLK_2: LED1.CO, LED2.CI
CLK_3: JP1.2, LED2.CO
DATA_1/MOSI: ICSP1.4, ICSP2.2 (MOSI), LED1.DI, U1.5 (PB0(MOSI))
DATA_2: LED1.DO, LED2.DI
DATA_3: JP1.3, LED2.DO
GND: C1.2, C2.2, D1.A, D2.A, ICSP1.6, ICSP2.5 (GND), JP1.4, JP-USB-TOP.GND, LED1.GND, LED2.GND, SW1.P$2 (2), U1.4 (GND)
MISO: ICSP1.1, ICSP2.3 (MISO), U1.6 (PB1(MISO))
N_RESET: ICSP1.5, ICSP2.1 (\RST), R4.1, SW1.P$1 (1), U1.1 (PB5(NRES))
USB_D_MINUS: R3.1, U1.2 (PB3(ADC3))
USB_D_MINUS_RAW: D2.C, JP-USB-TOP.USB_M (D-), R1.2, R3.2
USB_D_PLUS: R2.2, U1.3 (PB4(ADC2))
USB_D_PLUS_RAW: D1.C, JP-USB-TOP.USB_P (D+), R2.1
VCC: C1.1, C2.1, ICSP1.2, ICSP2.6 (VCC), JP1.1, JP-USB-TOP.5V (VBUS), LED1.VCC, LED2.VCC, R1.1, R4.2, U1.8 (VCC)

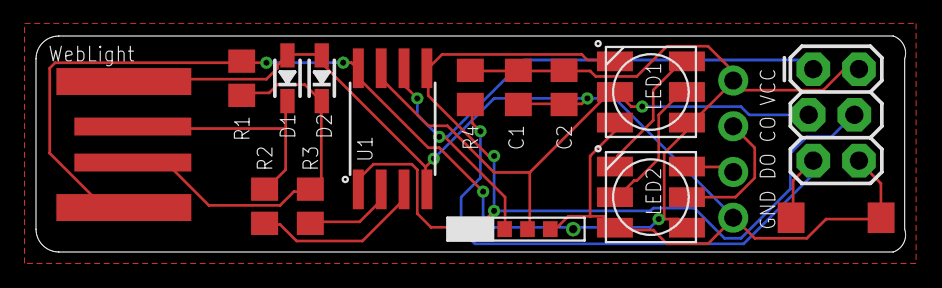
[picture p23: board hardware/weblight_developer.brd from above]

Board: 2 copper layers, 48.3 x 12.0 mm, 16 parts (0 on the bottom side), 14 nets.

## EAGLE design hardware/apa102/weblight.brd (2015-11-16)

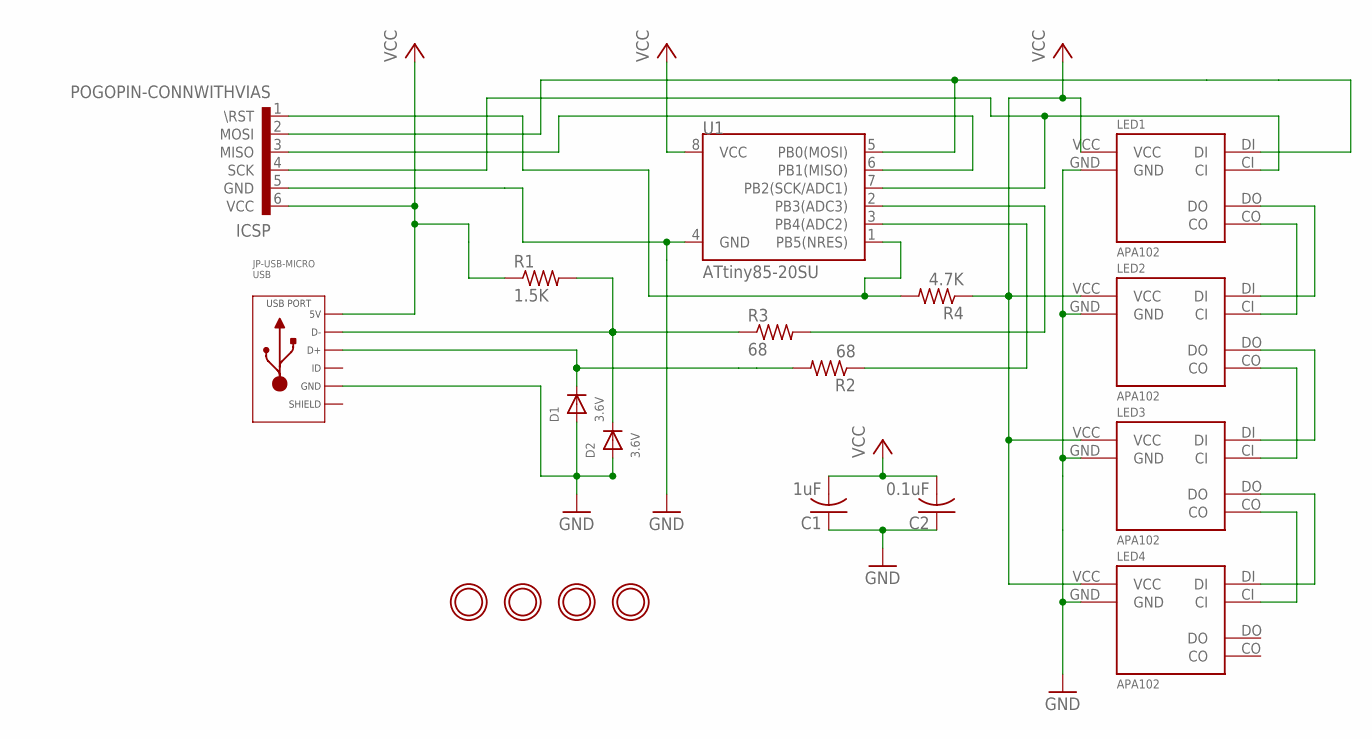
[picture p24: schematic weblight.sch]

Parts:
C1: 1uF; C0402
C2: 0.1uF; C0402
D1, D2: 3.6V; SOD-523
HOLE1, HOLE2, HOLE3, HOLE4: MOUNTINGHOLE2.0; MOUNTINGHOLE_2.0_PLATED
ICSP: POGOPIN-CONNWITHVIAS; POGOPROG-CONN-0H
JP-USB-MICRO: USB; MICROUSB-RIGHT
LED1, LED2, LED3, LED4: APA102
R1: 1.5K; R0402
R2, R3: 68; R0402
R4: 4.7K; R0402
U1: ATtiny85-20SU; SO08-EIAJ

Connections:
CLK_1/SCK: ICSP.4 (SCK), LED1.CI, U1.7 (PB2(SCK/ADC1))
CLK_2: LED1.CO, LED2.CI
CLK_3: LED2.CO, LED3.CI
CLK_4: LED3.CO, LED4.CI
DIN_1/MOSI: ICSP.2 (MOSI), LED1.DI, U1.5 (PB0(MOSI))
DIN_2: LED1.DO, LED2.DI
DIN_3: LED2.DO, LED3.DI
DIN_4: LED3.DO, LED4.DI
GND: C1.1, C2.1, D1.A, D2.A, ICSP.5 (GND), JP-USB-MICRO.5 (GND), LED1.GND, LED2.GND, LED3.GND, LED4.GND, U1.4 (GND)
MISO: ICSP.3 (MISO), U1.6 (PB1(MISO))
N_RESET: ICSP.1 (\RST), R4.2, U1.1 (PB5(NRES))
SLD: JP-USB-MICRO.S1 (SLD), JP-USB-MICRO.S2 (SLD), JP-USB-MICRO.S3 (SLD), JP-USB-MICRO.S4 (SLD), JP-USB-MICRO.S5 (SLD), JP-USB-MICRO.S6 (SLD)
USB_D_MINUS: R3.2, U1.2 (PB3(ADC3))
USB_D_MINUS_RAW: D2.K (C), JP-USB-MICRO.2 (D-), R1.2, R3.1
USB_D_PLUS: R2.1, U1.3 (PB4(ADC2))
USB_D_PLUS_RAW: D1.K (C), JP-USB-MICRO.3 (D+), R2.2
VCC: C1.2, C2.2, ICSP.6 (VCC), JP-USB-MICRO.1 (5V), LED1.VCC, LED2.VCC, LED3.VCC, LED4.VCC, R1.1, R4.1, U1.8 (VCC)

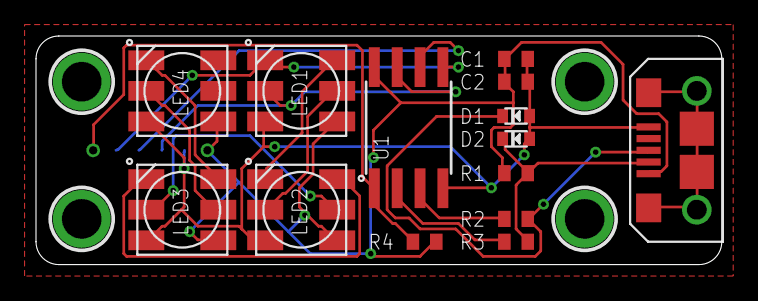
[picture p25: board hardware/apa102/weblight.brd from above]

Board: 2 copper layers, 38.1 x 12.7 mm, 19 parts (1 on the bottom side), 17 nets.

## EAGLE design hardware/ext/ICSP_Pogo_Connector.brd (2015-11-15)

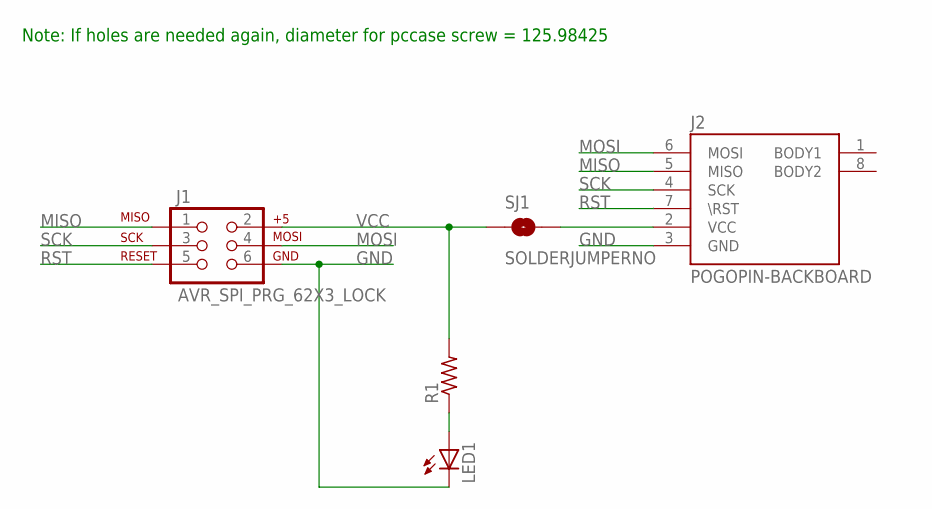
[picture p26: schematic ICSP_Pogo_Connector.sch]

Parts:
J1: AVR_SPI_PRG_62X3_LOCK; 2X3_LOCK
J2: POGOPIN-BACKBOARD; POGOPROG-BACKMOUNT
LED1: LED0603; LED-0603
R1: R-US_R0603; R0603
SJ1: SOLDERJUMPERNO; SJ_2S-NO

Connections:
GND: J1.6, J2.3 (GND), LED1.C
MISO: J1.1, J2.5 (MISO)
MOSI: J1.4, J2.6 (MOSI)
unnamed: J2.2 (VCC), SJ1.2
unnamed: LED1.A, R1.1
RST: J1.5, J2.7 (\RST)
SCK: J1.3, J2.4 (SCK)
VCC: J1.2, R1.2, SJ1.1

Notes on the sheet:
Note: If holes are needed again, diameter for pccase screw = 125.98425

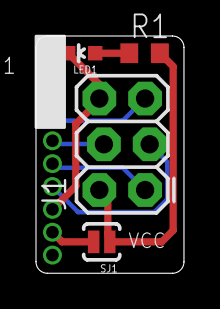
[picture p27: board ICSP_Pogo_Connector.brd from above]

Board: 2 copper layers, 8.2 x 13.2 mm, 6 parts (1 on the bottom side), 8 nets.

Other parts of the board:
U$2: POGOPROG_LOGO

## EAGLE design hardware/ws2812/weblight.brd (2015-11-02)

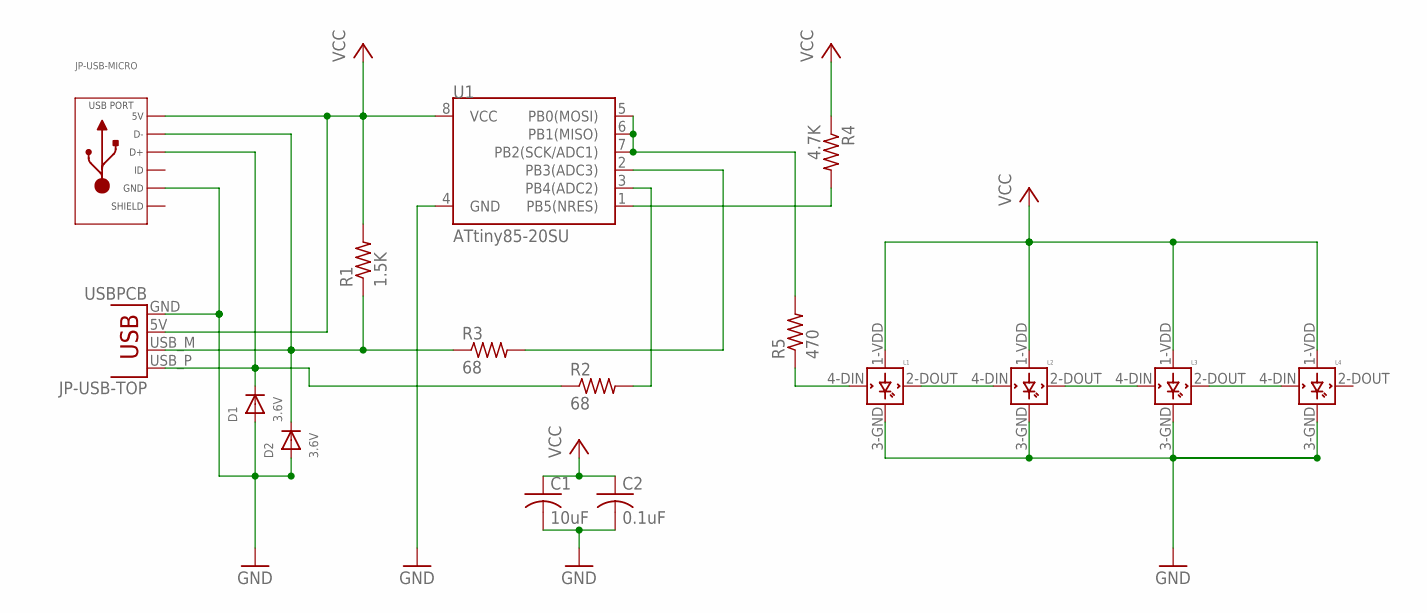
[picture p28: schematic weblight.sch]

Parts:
C1: 10uF; C0402
C2: 0.1uF; C0402
D1, D2: 3.6V; SOD-523
JP-USB-MICRO: USB_MICRO_RIGHT; MICROUSB-RIGHT
JP-USB-TOP: USBPCB; USB-A-PCB
L1, L2, L3, L4: WS2812B
R1: 1.5K; R0402
R2, R3: 68; R0402
R4: 4.7K; R0402
R5: 470; R0402
U1: ATtiny85-20SU; SO08-EIAJ

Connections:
DIN_1: L1.4-DIN (DIN), R5.1
DIN_2: L1.2-DOUT (DOUT), L2.4-DIN (DIN)
DIN_3: L2.2-DOUT (DOUT), L3.4-DIN (DIN)
DIN_4: L3.2-DOUT (DOUT), L4.4-DIN (DIN)
DIN_RAW: R5.2, U1.5 (PB0(MOSI)), U1.6 (PB1(MISO)), U1.7 (PB2(SCK/ADC1))
GND: C1.2, C2.2, D1.A, D2.A, JP-USB-MICRO.5 (GND), JP-USB-TOP.GND, L1.3-GND (GND), L2.3-GND (GND), L3.3-GND (GND), L4.3-GND (GND), U1.4 (GND)
N_RESET: R4.2, U1.1 (PB5(NRES))
SLD: JP-USB-MICRO.S1 (SLD), JP-USB-MICRO.S2 (SLD), JP-USB-MICRO.S3 (SLD), JP-USB-MICRO.S4 (SLD), JP-USB-MICRO.S5 (SLD), JP-USB-MICRO.S6 (SLD)
USB_D_MINUS: R3.2, U1.2 (PB3(ADC3))
USB_D_MINUS_RAW: D2.K (C), JP-USB-MICRO.2 (D-), JP-USB-TOP.USB_M (D-), R1.1, R3.1
USB_D_PLUS: R2.2, U1.3 (PB4(ADC2))
USB_D_PLUS_RAW: D1.K (C), JP-USB-MICRO.3 (D+), JP-USB-TOP.USB_P (D+), R2.1
VCC: C1.1, C2.1, JP-USB-MICRO.1 (5V), JP-USB-TOP.5V (VBUS), L1.1-VDD (VDD), L2.1-VDD (VDD), L3.1-VDD (VDD), L4.1-VDD (VDD), R1.2, R4.1, U1.8 (VCC)

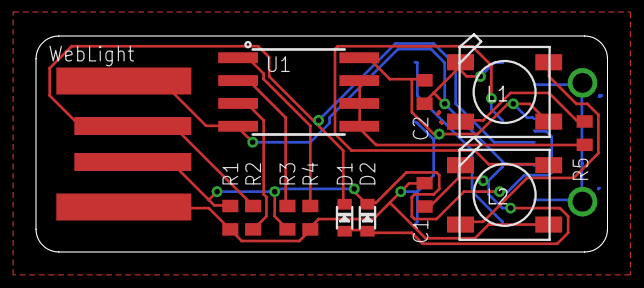
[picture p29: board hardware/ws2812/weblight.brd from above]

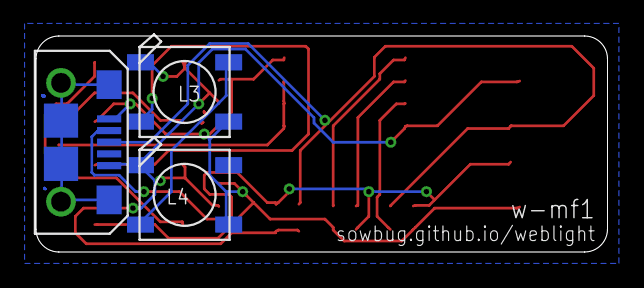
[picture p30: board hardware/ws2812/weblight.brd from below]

Board: 2 copper layers, 31.8 x 12.0 mm, 16 parts (3 on the bottom side), 13 nets.

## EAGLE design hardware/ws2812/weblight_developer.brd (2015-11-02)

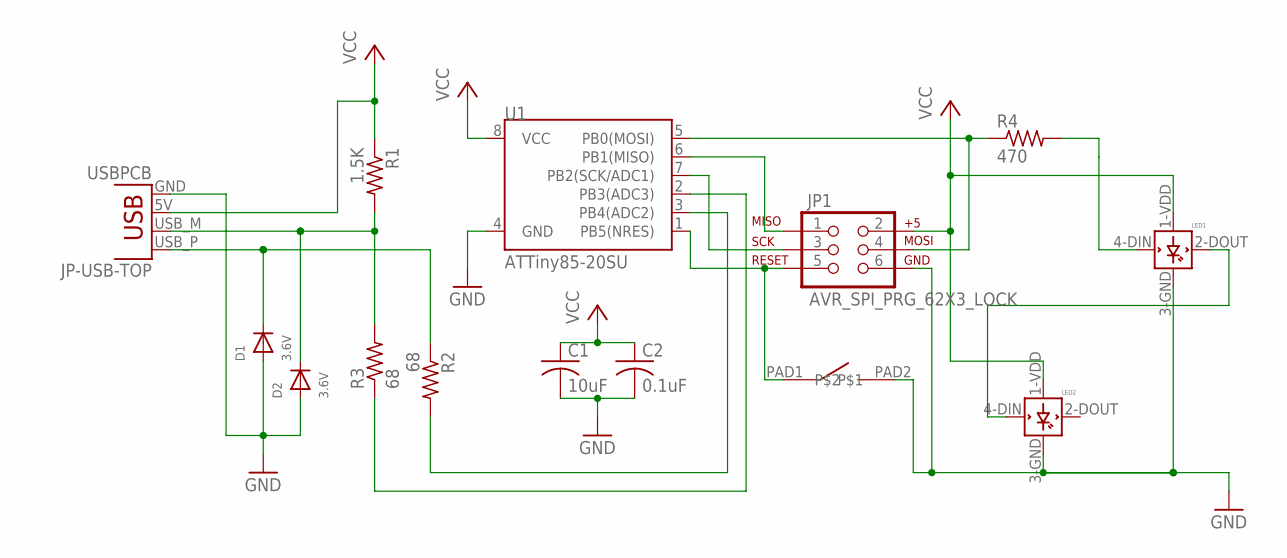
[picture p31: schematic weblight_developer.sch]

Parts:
C1: 10uF; C0805
C2: 0.1uF; C0805
D1, D2: 3.6V; SOD-323
JP1: AVR_SPI_PRG_62X3_LOCK; 2X3_LOCK
JP-USB-TOP: USBPCB; USB-A-PCB
LED1, LED2: WS2812B
R1: 1.5K; R0805
R2, R3: 68; R0805
R4: 470; R0805
SW_RESET: BUTTON_TD-85XU
U1: ATTiny85-20SU; SO08-EIAJ

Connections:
DIN_1: LED1.4-DIN (DIN), R4.2
DIN_2: LED1.2-DOUT (DOUT), LED2.4-DIN (DIN)
GND: C1.2, C2.2, D1.A, D2.A, JP1.6, JP-USB-TOP.GND, LED1.3-GND (GND), LED2.3-GND (GND), SW_RESET.PAD2, U1.4 (GND)
MISO: JP1.1, U1.6 (PB1(MISO))
MOSI/DIN_RAW: JP1.4, R4.1, U1.5 (PB0(MOSI))
unnamed: JP1.3, U1.7 (PB2(SCK/ADC1))
RESET: JP1.5, SW_RESET.PAD1, U1.1 (PB5(NRES))
USB_D_MINUS: R3.1, U1.2 (PB3(ADC3))
USB_D_MINUS_RAW: D2.C, JP-USB-TOP.USB_M (D-), R1.2, R3.2
USB_D_PLUS: R2.2, U1.3 (PB4(ADC2))
USB_D_PLUS_RAW: D1.C, JP-USB-TOP.USB_P (D+), R2.1
VCC: C1.1, C2.1, JP1.2, JP-USB-TOP.5V (VBUS), LED1.1-VDD (VDD), LED2.1-VDD (VDD), R1.1, U1.8 (VCC)


Board: 2 copper layers, 43.2 x 12.0 mm, 14 parts (0 on the bottom side), 12 nets.

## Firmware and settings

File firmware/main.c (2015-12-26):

// Copyright 2015 Mike Tsao
//
// WebLight firmware
// https://github.com/sowbug/weblight

#include <avr/interrupt.h>  // for sei()
#include <avr/wdt.h>
#include <util/delay.h>  // for _delay_ms()

#include "app.h"
#include "usbdrv.h"

int __attribute__((noreturn)) main(void) {
  wdt_enable(WDTO_1S);
  usbInit();

  // From http://vusb.wikidot.com/examples:
  //
  // Enumeration is performed only when the device is connected to the
  // bus. If the device has a CPU reset, its memory is usually cleared
  // and the assigned address is lost. Since the host does not know
  // that the device had a reset, it still addresses the device under
  // its old address, but the device won't answer.

  // It is therefore useful to simulate a device disconnect in the
  // device initialization code. This ensures that host and device
  // agree on the same address. You should therefore insert
  // [disconnect/reconnect] code in your initialization (best before
  // usbInit() because the USB interrupt must be disabled during
  // disconnect state):
  usbDeviceDisconnect();

  // Now delay to ensure the host notices that the device was
  // unplugged.
  uint8_t disconnect_delay_ms = 250;
  while (disconnect_delay_ms-- > 0) {
    _delay_ms(1);
  }

  sei();
  usbDeviceConnect();

  App app;
  AppInit(&app);

  while (1) {
    usbPoll();
    AppRun(&app);
    wdt_reset();
  }
}

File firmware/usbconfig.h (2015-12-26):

// Copyright 2015 Mike Tsao
//
// WebLight firmware
// https://github.com/sowbug/weblight

#ifndef __usbconfig_h_included__
#define __usbconfig_h_included__

#ifndef __ASSEMBLER__
#include "led_control.h"
#endif

/* ---------------------------- Hardware Config ---------------------------- */

#define USB_CFG_IOPORTNAME      B
/* This is the port where the USB bus is connected. When you configure it to
 * "B", the registers PORTB, PINB and DDRB will be used.
 */
#define USB_CFG_DMINUS_BIT      3
/* This is the bit number in USB_CFG_IOPORT where the USB D- line is connected.
 * This may be any bit in the port.
 */
#define USB_CFG_DPLUS_BIT       4
/* This is the bit number in USB_CFG_IOPORT where the USB D+ line is connected.
 * This may be any bit in the port. Please note that D+ must also be connected
 * to interrupt pin INT0! [You can also use other interrupts, see section
 * "Optional MCU Description" below, or you can connect D- to the interrupt, as
 * it is required if you use the USB_COUNT_SOF feature. If you use D- for the
 * interrupt, the USB interrupt will also be triggered at Start-Of-Frame
 * markers every millisecond.]
 */
#define USB_CFG_CLOCK_KHZ       (F_CPU/1000)
/* Clock rate of the AVR in kHz. Legal values are 12000, 12800, 15000, 16000,
 * 16500, 18000 and 20000. The 12.8 MHz and 16.5 MHz versions of the code
 * require no crystal, they tolerate +/- 1% deviation from the nominal
 * frequency. All other rates require a precision of 2000 ppm and thus a
 * crystal!
 * Since F_CPU should be defined to your actual clock rate anyway, you should
 * not need to modify this setting.
 */
#define USB_CFG_CHECK_CRC       0
/* Define this to 1 if you want that the driver checks integrity of incoming
 * data packets (CRC checks). CRC checks cost quite a bit of code size and are
 * currently only available for 18 MHz crystal clock. You must choose
 * USB_CFG_CLOCK_KHZ = 18000 if you enable this option.
 */

/* ----------------------- Optional Hardware Config ------------------------ */

/* #define USB_CFG_PULLUP_IOPORTNAME   D */
/* If you connect the 1.5k pullup resistor from D- to a port pin instead of
 * V+, you can connect and disconnect the device from firmware by calling
 * the macros usbDeviceConnect() and usbDeviceDisconnect() (see usbdrv.h).
 * This constant defines the port on which the pullup resistor is connected.
 */
/* #define USB_CFG_PULLUP_BIT          4 */
/* This constant defines the bit number in USB_CFG_PULLUP_IOPORT (defined
 * above) where the 1.5k pullup resistor is connected. See description
 * above for details.
 */

/* --------------------------- Functional Range ---------------------------- */
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

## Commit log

2015-09-29 v0.0.0.1: ground plane
    Added vRestrict over USB area.
    Rerouted without ground planes, then readded.
    Added board images and lists.
    [usb-led.brd]
2015-09-30 Depend on SOIC clip. Add MacroFab dependencies (micro USB).
    [usb-led.brd, usb-led.sch]
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2015-10-19 Forgot about RC oscillator calibration
    [main.c, usbconfig.h]
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2015-10-24 Move out oscillator calibration
    [main.c]
2015-10-26 #2: Remove bottom USB connector to avoid short
    [weblight.brd, weblight.sch]
2015-10-26 #17: add 470 ohm resistor before first DIN
    [weblight.brd, weblight.sch]
2015-10-26 Fork into production and developer versions.
    [weblight_developer.brd, weblight_developer.sch]
2015-10-26 Changes to prod circuit.
    [weblight.brd, weblight.sch]
2015-10-26 Fix net names.
    [weblight.brd, weblight.sch]
2015-10-26 Developer board changes.
    Convert every 0402 SMD to 0805.
    [weblight_developer.brd, weblight_developer.sch]
2015-10-26 osh3 rc1
    [weblight_developer.brd, weblight_developer.sch]
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2015-10-26 mf3 rc1
    Pullup resistor on NRES
    [weblight.brd, weblight.sch]
2015-10-26 #19: Update prod label
    [weblight.brd]
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2015-10-27 Cute overload: blink 3x before reset
    [main.c]
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2015-10-27 First pass at WinUSB descriptor (doesn't work yet)
    [usbconfig.h]
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2015-10-29 Maybe fix #20 (WinUSB)
    https://social.msdn.microsoft.com/Forums/sqlserver/en-US/ae64282c-3bc3-49af-8391-4d174479d9e7/microsoft-os-20-descriptors-not-working-on-an-interface-of-a-composite-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
    QUOTE
    It looks like we'll need to update the MSOS 2.0 Descriptor docs to match
    the implementation in USBCCGP. The bConfigurationValue in the
    configuration subset header should actually just be an index value, not
    the configuration value.
    Specifically it's the index value passed to GET_DESCRIPTOR to retrieve
    the configuration descriptor.
    Try changing the value to 0 and see if that resolves the issue. Sorry
    for the confusion.
    /QUOTE
2015-10-31 Fix #15: read descriptors from PROGMEM to usbFunctionSetup()
    [usbconfig.h]
2015-11-01 Move developer board to APA102C
    [weblight_developer.brd, weblight_developer.sch]
2015-11-01 Switch over production to APA102C
    [weblight.brd, weblight.sch]
2015-11-01 Miter board
    [weblight_developer.brd]
2015-11-01 More work on #13 with many thanks to @Bluebie.
    - Remove USB_POST_TX_HOOK, which was the right idea but could be
    done more frequently after *any* frame from the host.
    - Switch interrupt to D- per V-USB advice in usbconfig.h to enable
    start-of-frame counter.
    - Enable USB_COUNT_SOF.
    - After usbPoll() in main loop, check sofCount and do LED work if it
    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
2015-11-02 Move around stuff to split out WS2812 and APA102 versions
    [weblight.brd, weblight.sch, weblight_developer.brd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]
2015-11-02 Separate LED type and adopt new board versioning scheme
    [weblight.brd, weblight.sch, weblight_developer.brd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]
2015-11-02 Adjust ground planes
    [weblight.brd, weblight_developer.brd]
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2015-11-02 Startup sequence was getting annoying. Shortened
    [main.c]
2015-11-15 Forgot ICSP
    [weblight.brd, weblight.sch]
2015-11-15 Thanks http://protofusion.org/
    [ICSP_Pogo_Connector.brd, ICSP_Pogo_Connector.sch]
2015-11-16 Substitute 6-pin pogo layout
    [weblight.brd, weblight.sch]
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2015-12-06 Stencil files
    [weblight_developer-bcream.dxf, weblight_developer-tcream.dxf]
2015-12-06 ws2812 version is obsolete. Rearrange
    [weblight.brd, weblight.sch, weblight_developer-bcream.dxf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]
2015-12-10 Fix make bug and remove WS2812 references
    [weblight.brd, weblight.sch, weblight_developer.brd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]
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2015-12-25 Fix transition math. Currently too big to flash
    [main.c]
2015-12-25 Half-fixed bug where COLOR doesn't work if transition sequence is happening
    [main.c]
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2015-12-25 Likely fix #25: USB_CFG_LONG_TRANSFERS had something to do with it
    [usbconfig.h]
2015-12-25 mf2 production 0805 - ordered from OSH & Seeed
    [weblight.brd, weblight.sch]
2015-12-26 NRES pullup 10K; big cap 1uF
    [weblight_developer.brd, weblight_developer.sch]
2015-12-26 Now that all boards have same # of LEDs, no need for multiple hex files
2015-12-26 Promote issue for getting boards
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2015-12-26 Fix #30: let hardware version bubble up from Makefile
    [usbconfig.h]
2016-01-08 Connectorless USB, longer board. Unrouted.
    - Two diodes to protect back connector. Thanks Passerby
    http://electronics.stackexchange.com/q/209941/84391
    - Moved C1/C2 closer to where they matter.
    - A few astute layout changes to facilitate future routing.
    [weblight.brd, weblight.sch]
2016-01-08 Checkpoint before routing
    [weblight.brd]
2016-01-08 Some manual routing. Mess
    [weblight.brd]
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2016-01-17 Better initial layout. Unrouted
    [weblight.brd]
2016-01-17 Got most of easy stuff routed.
    [weblight.brd]
2016-01-17 Checkpoint. Not all routed yet
    [weblight.brd]
2016-01-17 Checkpoint #2, all but connectors
    [weblight.brd]
2016-01-17 Checkpoint #3, some connectors
    [weblight.brd]
2016-01-17 Checkpoint #4, one airwire left
    [weblight.brd]
2016-01-17 All routed?
    [weblight.brd]
2016-01-17 Move labels around
    [weblight.brd]
2016-01-17 Separate version text into something more manageable
    [weblight.brd]
2016-01-18 Routing refinements and re-enabling of diodes
    - Optimized needless turns by embedding them into pads
    - Fixed horrible error that reintroduced short prevented by D3/D4
    - Moved vias away from LED1
    - Shuffled around other vias to stay away from traces
    - Supply LED1 from C1 rather than post-C2
    - Removed bend in C2 trace (magic I don't understand)
    - Fattened up all supply traces
    [weblight.brd, weblight.sch]
2016-01-18 Remove one more needless kink
    [weblight.brd]
2016-01-18 More mitering
    [weblight.brd]
2016-01-19 0.9.2.0 + http://www.hackvana.com/ files
    [weblight.brd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]
2016-01-19 Remove tCream from ProtoProg footprint
    [weblight.brd, weblight.sch]
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2016-01-22 Fix #32. 0.9.3
    [weblight.brd, weblight.sch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]
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2016-03-01 0.9.3, labels on back aligned
    [weblight.brd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]
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2016-03-02 Updated with dirtypcbs.com .cam
    [weblight-Vcut.gbr, weblight.GBL, weblight.GBO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]
2016-03-26 Stencil for 0.9.3
    [weblight-bcream.dxf, weblight-tcream.dxf]
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2016-03-28 Prevent navigation when clicking #lightConnect.
    If the frame is allowed to navigate then the navigator.usb.requestDevice
    request will be cancelled immediately. Use event.preventDefault() to
    make this link act more like a button.
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2016-08-21 Add fiducials. Move bottom text. Handle DirtyPCB DRU. Ver 1.0
    [weblight.brd, weblight.sch]
2016-08-21 1.0 with blank soldermask images
    See https://github.com/hadleyrich/GerbLook/issues/15 for issue
    [weblight.GBL, weblight.GBO, weblight.GBP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]
2016-08-23 Added 145x140mm frame
    From Stijn Kuipers
    http://blog.thisisnotrocketscience.nl/projects/pcb-panelizer-beta/
    Unpublished tool that generates a panel frame of a specified size
    with a title and fiducials.
    This frame is 145x140mm and perfectly fits a 3x10 matrix of
    WebLight 1.0 with 2mm connecting tabs.
    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
    [wl_frame.gbl, wl_frame.gbo, wl_frame.gbs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]
2016-08-23 Panelized Gerbers
    3x10 using 145x140mm frame.
    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
    [combined.GKO, combined.gbl, combined.gbo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]
2016-08-24 BOM 1.0 DigiKey
    [DigiKey_BOM-1.0.csv]
2016-08-26 Fix #39: one fiducial under U1; 1.0.1
    [weblight.brd, weblight.sch]
2016-08-27 Demote 1.0 to 1.0-rc1
    [combined.GKO, combined.gbl, combined.gbo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]
2016-08-27 Flip ISP; hide fiducial; real 1.0 (I hope)
    [combined.GKO, combined.gbl, combined.gbo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]
2016-08-27 1.0 as sent to PCBCart for quotation
    [DigiKey_BOM-1.0.csv, Mouser_BOM-1.0.xls, PCBCart_BOM-WebLight-1.0.xlsx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]
2016-08-28 Save files sent to PCBCART for quote
    [PCBCart_BOM-WebLight-1.0.xlsx]
2016-09-14 Reset device after regenerating serial
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2016-11-12 Further SK9822 hacking.
    https://cpldcpu.wordpress.com/2014/11/30/understanding-the-apa102-superled/
    comments provided further insight. Still not sure if this is correct.
    [light_apa102.c]
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2016-12-15 Use device serialNumber as dictionary key.
    In 9b22f8a0e0ee45612cea9dfeecd1b0f1167b15d1 when I was preparing for the
    removal of the guid attribute from USBDevice I assumed that the
    USBDevice object itself could be used as a functional Object key. This
    is not the case (all objects stringify the to same value). So instead we
    should be using the device serial number since all WebLights have a
    valid and unique serial number.
    This resolves issue #41.
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

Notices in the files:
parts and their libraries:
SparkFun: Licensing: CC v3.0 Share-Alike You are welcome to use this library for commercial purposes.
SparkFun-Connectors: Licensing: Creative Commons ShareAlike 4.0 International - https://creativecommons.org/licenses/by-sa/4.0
